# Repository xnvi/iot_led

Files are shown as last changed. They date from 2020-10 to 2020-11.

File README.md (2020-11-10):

# 1 项目简介

## 1.1 项目介绍
台灯是日常使用频率最高的电器，将给大家介绍如何制作一款可以使用微信小程序进行远程控制的智能台灯。这款台灯操作简便，可以灵活调节亮度、色温，开发板上的OLED显示屏能够实时显示台灯的状态，同时预留了WS2812灯带接口，内置多种彩灯模式，可以做氛围灯使用。所有软硬件设计全部开源，动手能力强的小伙伴也可以在此基础上改造属于你自己的智能台灯。相关问题解答参见文末Q&A章节。

## 1.2 材料清单
TencentOS_tiny_EVB_G0 开发板 x1
E53接口LED驱动模块 x1 （需要自己焊接，详细物料清单参见下方链接）
椴木板外壳一套 （需要根据图纸自己加工）
双色温LED灯管 x2 （文中同款搜索“Rohm led灯条”）
150 * 20 * 6 mm 散热器 x2
12V 1A 电源 x1 （保护环境，可以使用旧路由器、电视盒子等的电源，输出电压12V，输出电流为1A或更高）
鹅颈管 x1
鹅颈管配套铁夹 x1
鹅颈管配套螺母若干
UHU胶、电线、焊锡、电烙铁、镊子、扳手等其他材料与工具

## 1.3 项目链接
视频演示  
https://www.bilibili.com/video/bv1BK411G7cn  

工程源码  
https://gitee.com/dma/iot_led.git  

电路图及PCB  
https://oshwhub.com/Code504/e53-kuo-zhan-mu-kuai_copy  

# 2 硬件制作

## 2.1 TOS_EVB_G0 开发板
TOS_EVB_G0 开发板是由腾讯TencentOS-tiny团队设计的一款物联网开发板，外观如下：  
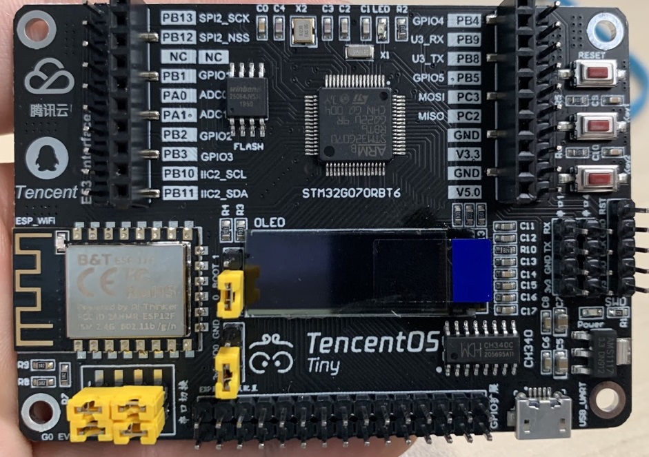
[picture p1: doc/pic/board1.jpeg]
  

* 主控芯片采用STM32G070RB，Flash空间为128KB、RAM空间为36KB；
* 板载腾讯云定制固件版ESP8266 WIFI模组；
* 板载E53传感器标准接口，方便连接各种E53传感器；
* 板载128*32 OLED显示屏幕；
* 板载8MB SPI Flash，可用于固件升级；
* 板载CH340转串口连接，可以使用一根USB线连接至电脑，查看串口日志；

下面是每部分详细的说明：  

开发板硬件电路详解  
(1) 最小系统电路  
最小系统部分由电源电路、时钟电路、Boot电路、复位电路、下载电路组成：  
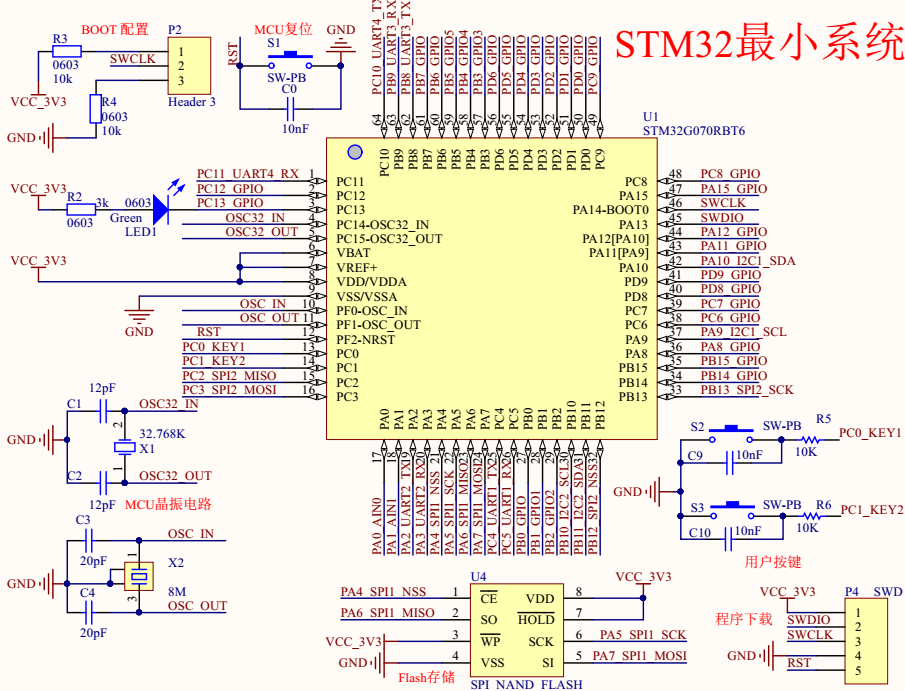
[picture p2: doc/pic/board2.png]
  

(2) WIFI电路  
WIFI部分包括ESP8266 WIFI模组供电电路、串口通信电路：  
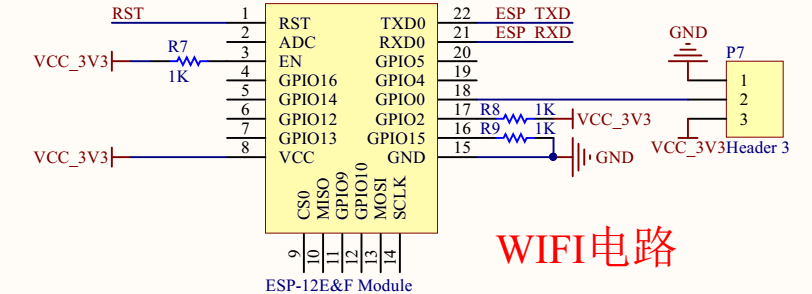
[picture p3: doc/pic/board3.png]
  

(3) E53扩展接口电路  
E53扩展接口供外部传感器连接，包括：一个串口、一个SPI接口、一个IIC接口、四个普通GPIO口、一个ADC模拟采集接口，一个DAC模拟输出接口，如图：  
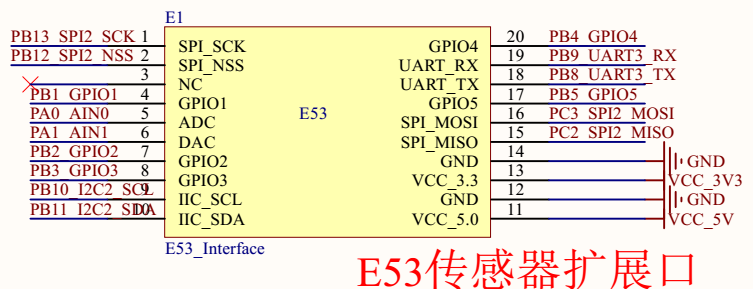
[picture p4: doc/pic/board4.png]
  

(4) USB转串口电路  
USB转串口电路将串口信息转换为USB口信号，使得开发板可以直接通过USB线连接至PC，在PC上使用串口助手查看日志：  
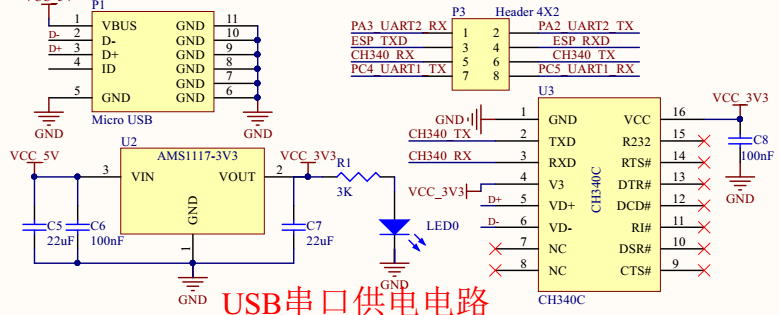
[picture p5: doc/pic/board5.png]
  

(5) OLED显示屏幕电路  
OLED屏幕部分包括OLED供电部分和通信部分：  
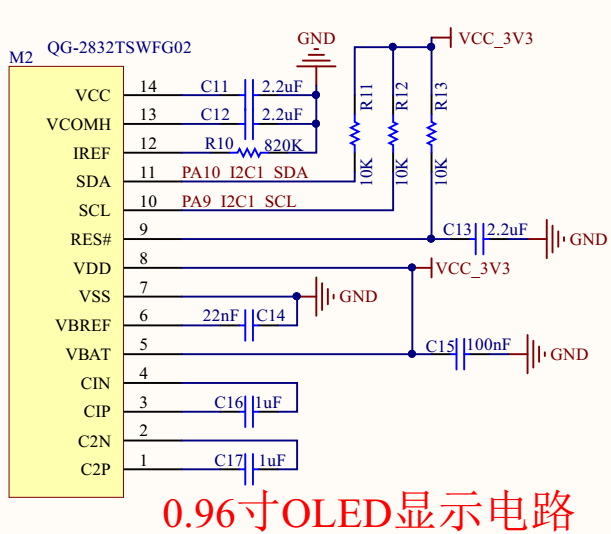
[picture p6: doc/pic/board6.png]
  

(6) 连接Micor USB线  
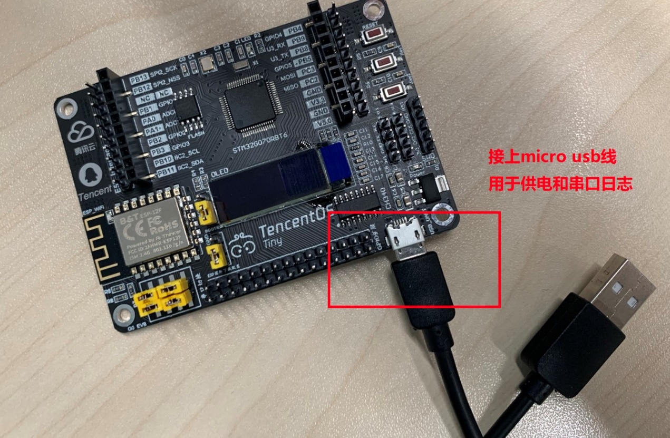
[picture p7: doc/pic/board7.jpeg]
  

(7) 连接ST-Link下载器  
开发板3v3---> STlink 3.3V  
开发板DIO---> STlink SWDIO  
开发板CLK---> STlink SWCLK  
开发板GND---> STlink GND  
请大家参考下图进行连接，千万不要接反接错，以免烧掉MCU  
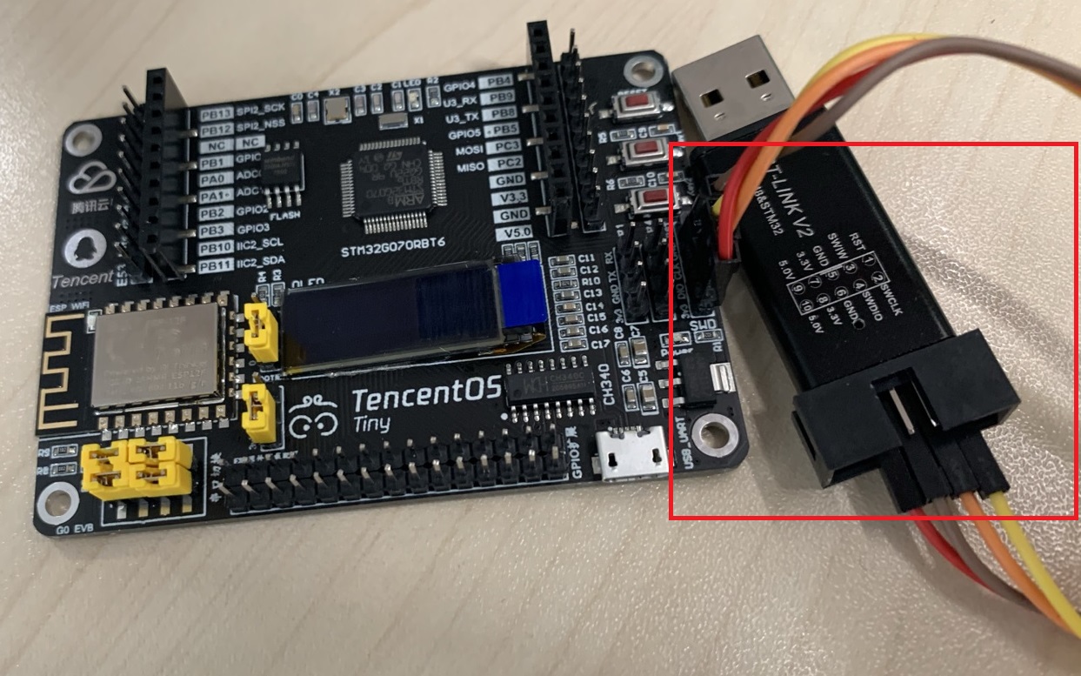
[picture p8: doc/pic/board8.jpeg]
  

## 2.2 台灯外壳及结构
首先需要购买鹅颈管、铁架、螺母等零件，规格如下:

鹅颈管建议选用40-60cm长，空心偏硬的鹅颈管，注意鹅颈管的内径不要太小，否则电线难以穿过，一定要选硬质鹅颈管，确保能够承受灯管的重量，两端螺纹规格分别为M10细牙扁头、M8细牙圆头，扁透这一端主要用于和夹子连接，圆头用于和灯管外壳连接，方便调整灯管角度，如果买不到同规格的尽量买参数相近的鹅颈管。  
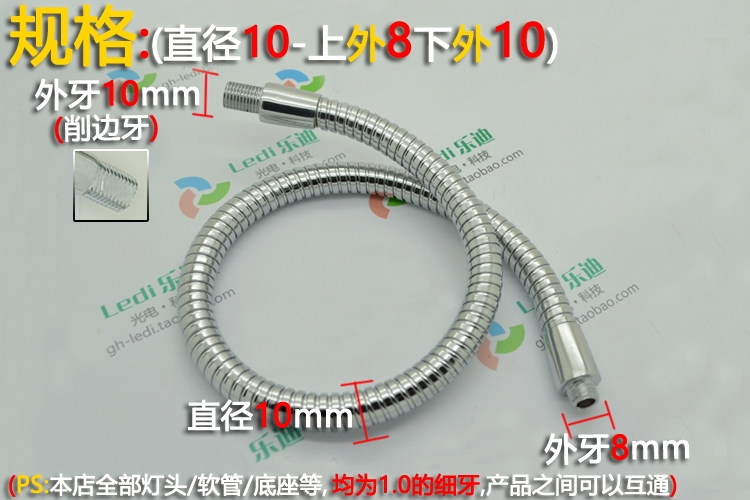
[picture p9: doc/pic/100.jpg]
  

铁夹子选购时注意开孔的形状，最好使用扁孔，这样方便固定鹅颈管，保证不会旋转，买不到扁孔和夹子和鹅颈管用圆孔的也行，记得把螺母稍微拧紧些  
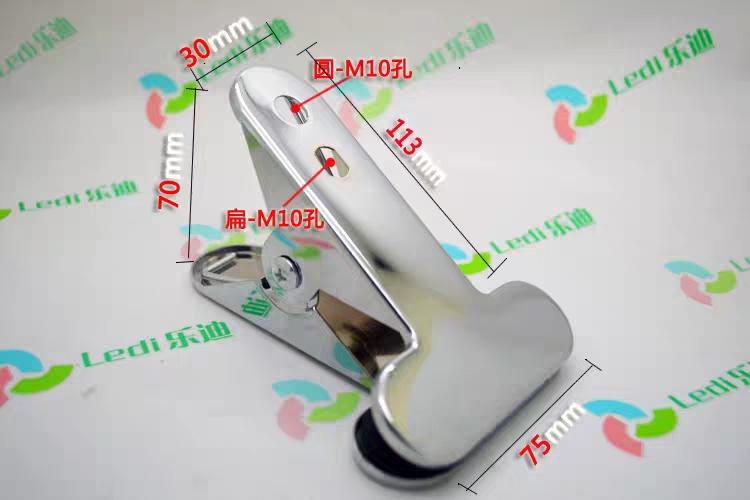
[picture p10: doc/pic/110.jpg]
  

当然还要记得买配套的螺母，有的店家会送  
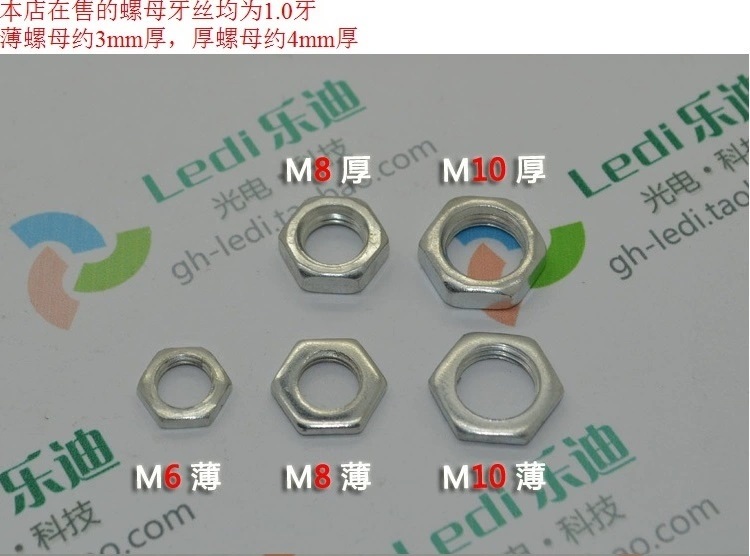
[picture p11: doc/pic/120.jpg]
  

灯管用704硅橡胶居中粘在散热器上，胶水一定不要挤得太多，胶水干透后焊接双色LED灯管（同款搜索“Rohm led灯条”），每个灯管的黄色与黄色并联，白色与白色并联  
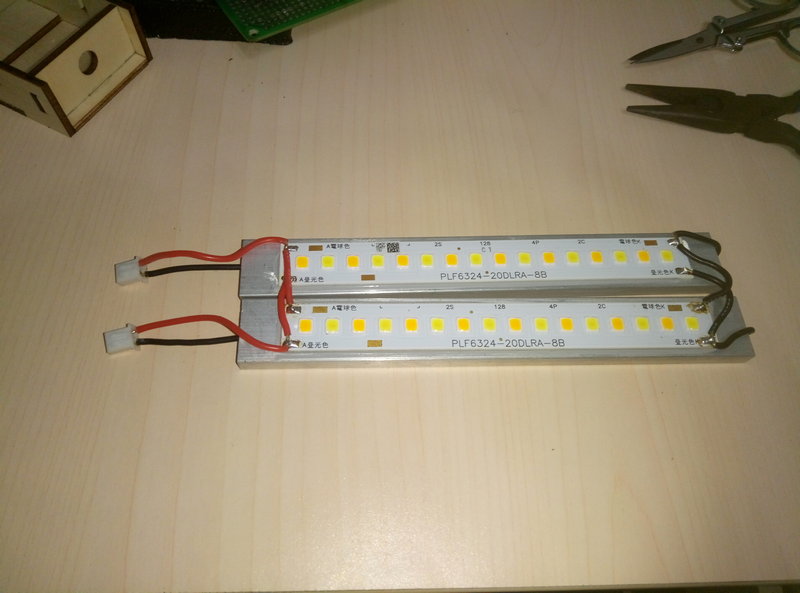
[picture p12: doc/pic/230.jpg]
  

下一步准备台灯外壳，图纸在源码的 doc 文件夹内，店家一般都是在一整块木板上进行切割，不论实际切割的大小都按整张板收费（不同店家收费可能不同，请自己与店家沟通），因此建议在一张图纸内多切割几个外壳，充分利用这块木板，减少浪费。如下图所示，这里在一块木板上切了4套台灯外壳和其他几个外壳  
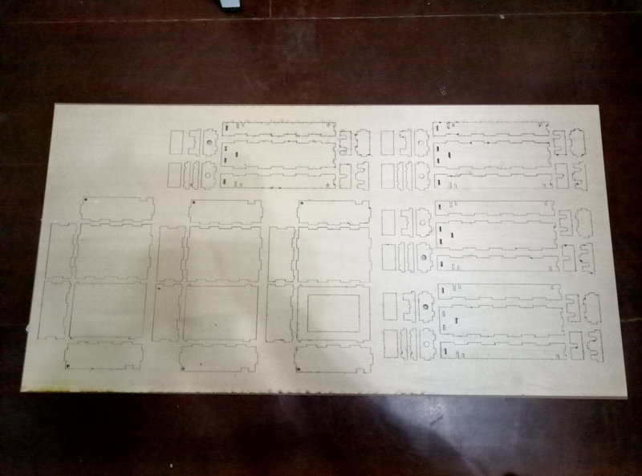
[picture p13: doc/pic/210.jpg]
  

实测单灯管照明有点暗，强烈建议用两个灯管，下图中标注的单灯管零件就不要使用了，B1和B2、G1和G2、H1和H2完全一样，F1和F2的区别在于开孔的直径不一样，一个是8mm，另一个是10mm，如果买不到同规格的鹅颈管方便替换使用
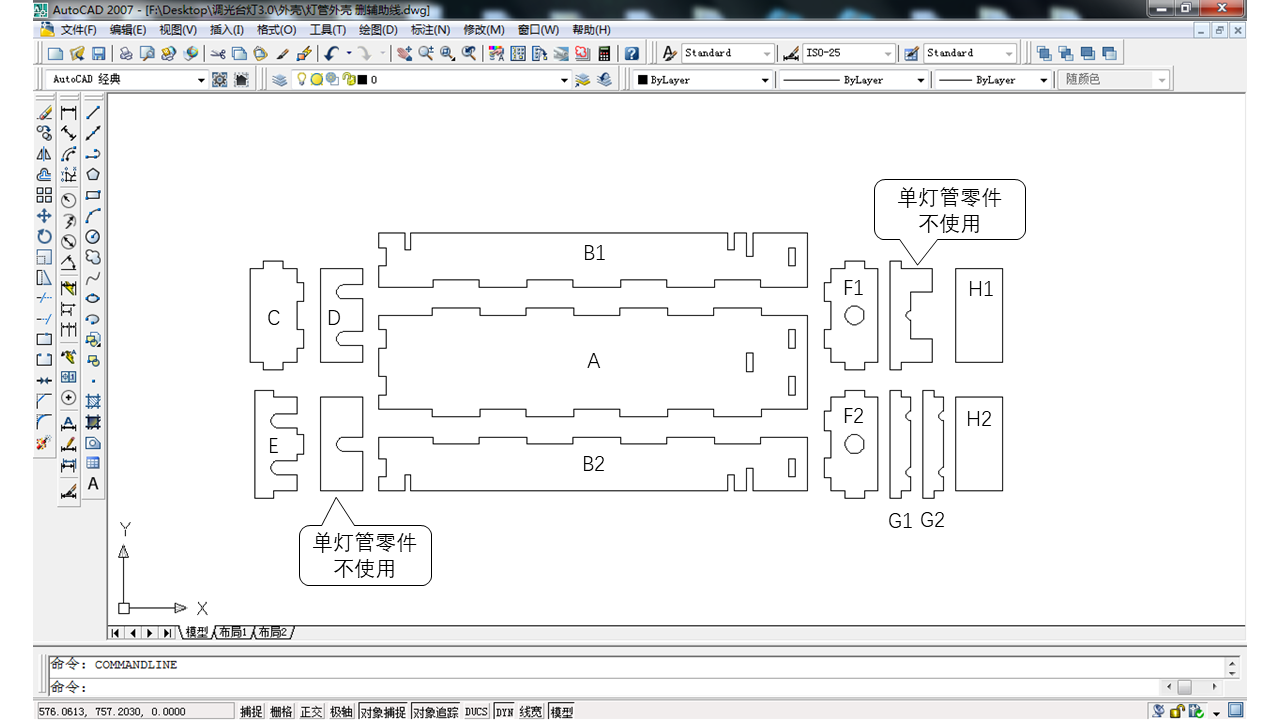
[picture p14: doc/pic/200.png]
  

将H1、H2粘在A上，这一步的主要目的是增加外壳的整体厚度，确保F1和F2开孔处有一定的轻度，否则开孔与边框离得太近很容易断
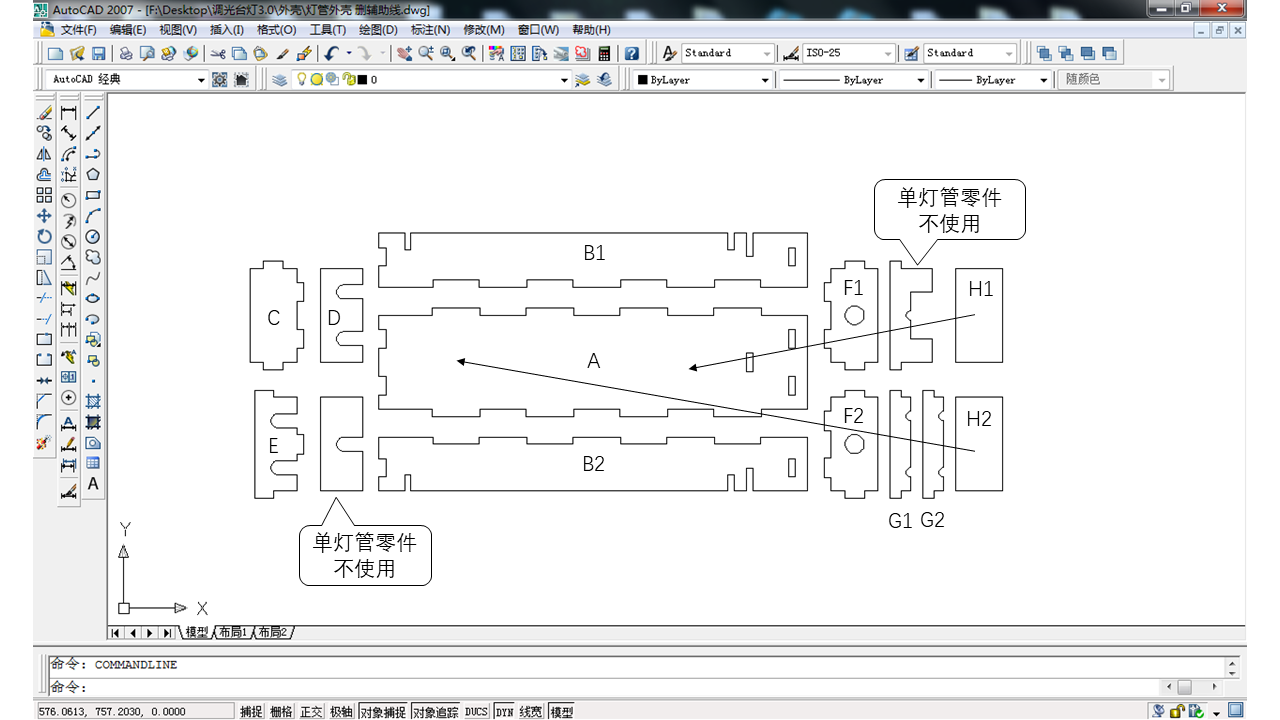
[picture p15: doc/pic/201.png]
  

将F1或F2按图纸箭头所示插入A对应孔内，B1和B2分别竖着安装在A的两侧，同时将F1或F2插入孔内，将C与D对齐粘在一起，将C按箭头所示进行组装  
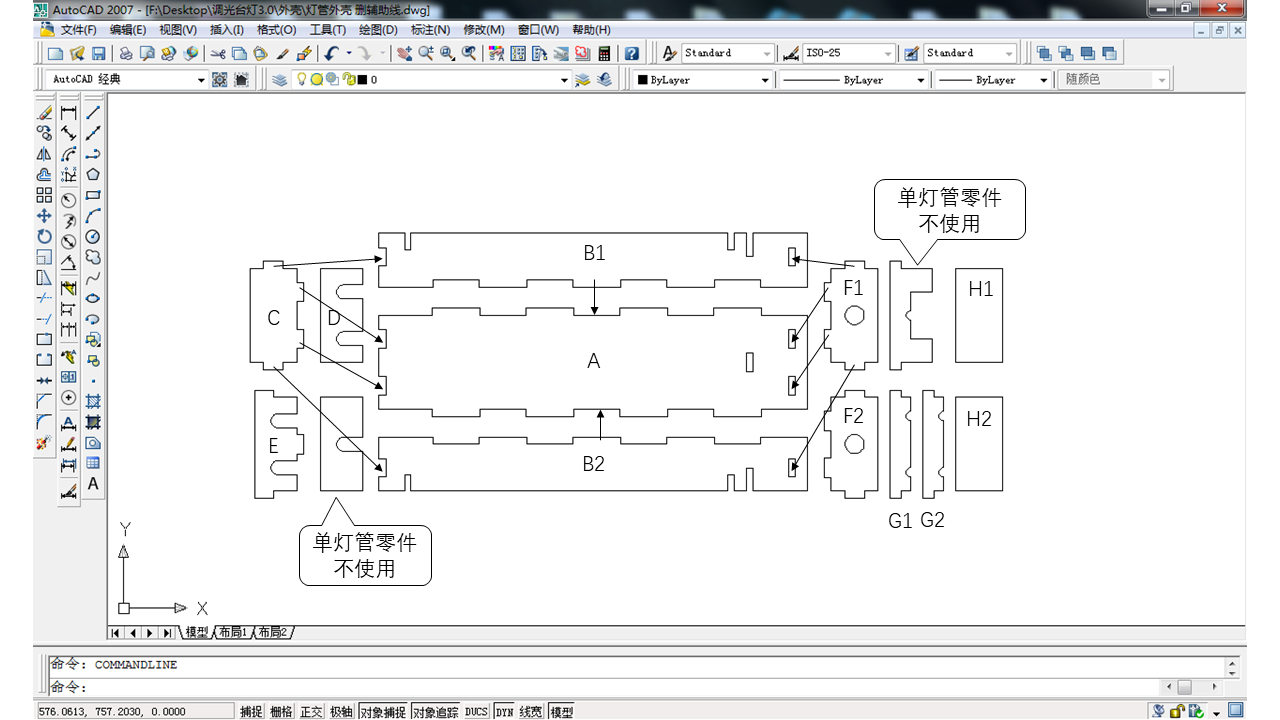
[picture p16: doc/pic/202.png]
  

等前几步的胶水干透以后，将灯管放入外壳，并将电线从E预留的孔中穿过，最后将E按照箭头所示进行安装  
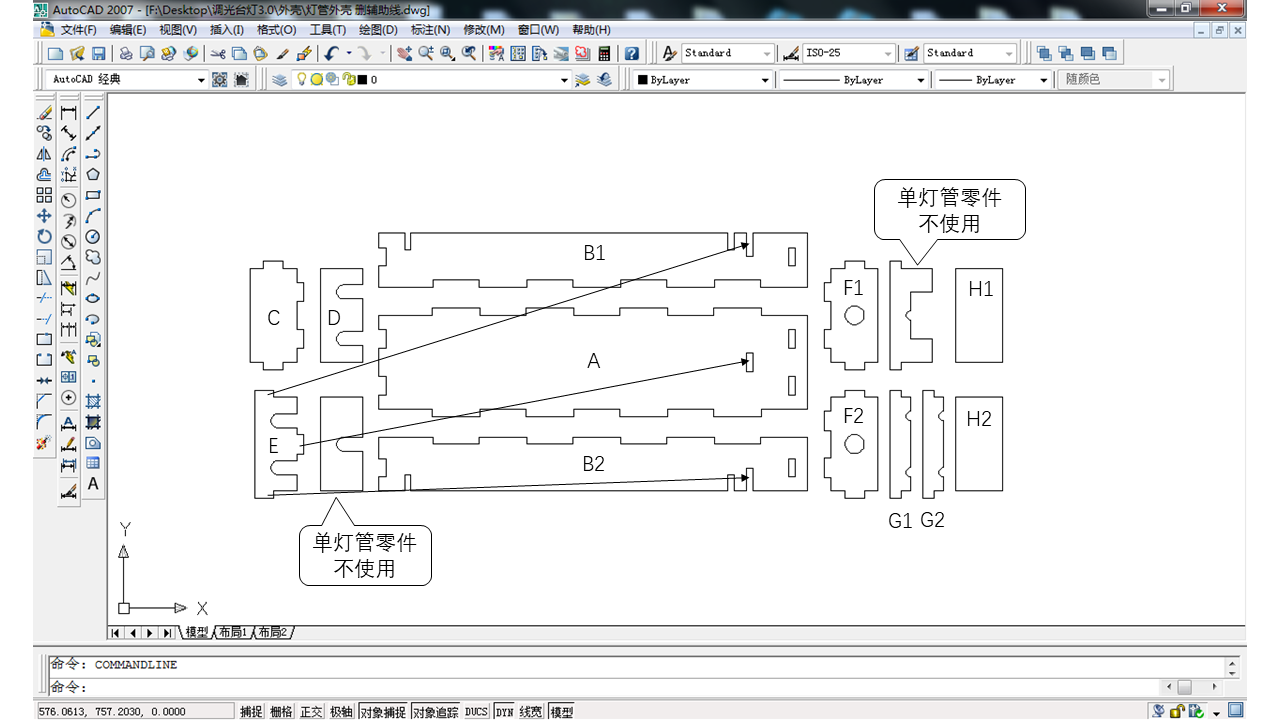
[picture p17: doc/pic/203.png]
  

最后将G1、G2按箭头所示进行安装，电线同样需要从预留的凹槽中穿过
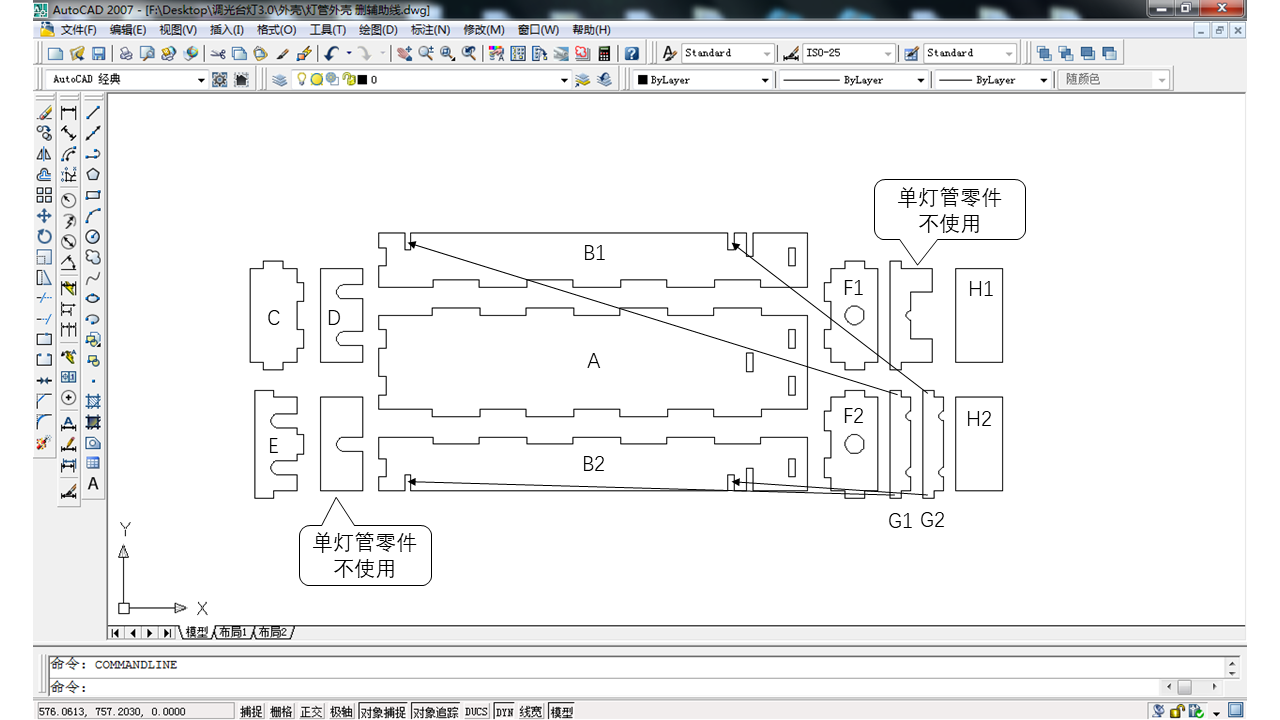
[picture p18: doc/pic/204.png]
  

在组装之前建议先按下图所示摆放一遍，确保没有拿错零件，最后再进行完整组装
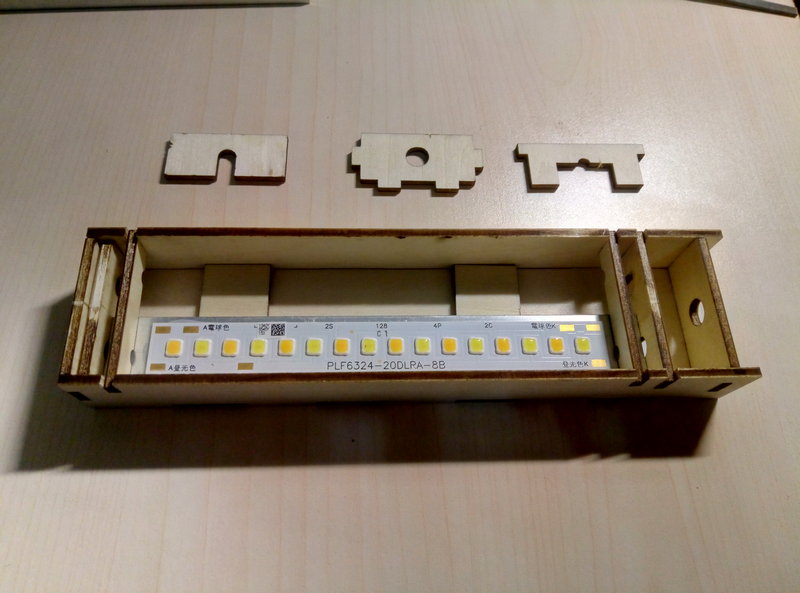
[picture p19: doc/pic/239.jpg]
  

最后组装完成是这样的，供大家参考，安装时一定注意先后顺序，提前把线、螺母穿好，避免返工  
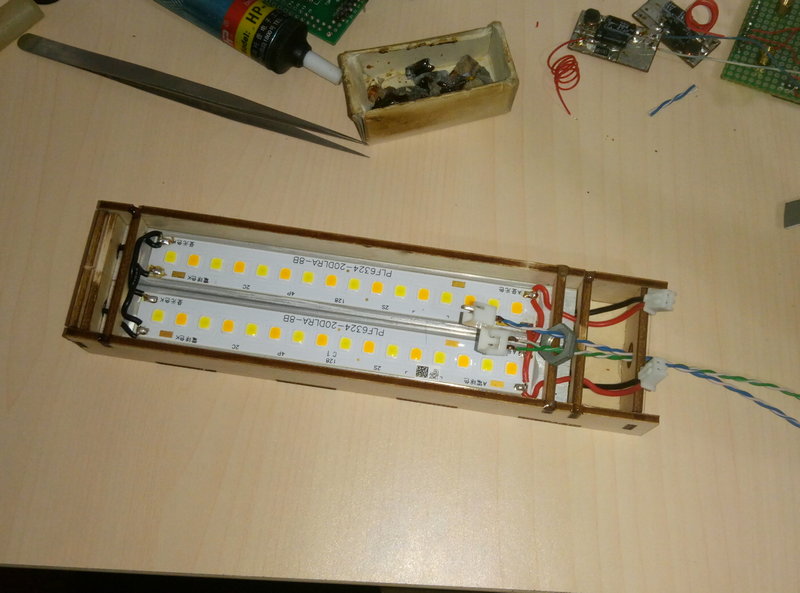
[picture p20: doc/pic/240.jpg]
  

上图有一个细节，我的外壳边缘比中间的零件大概高出2mm，预留用于安装透明外壳。如果买了什么东西的包装盒是塑料磨砂材质，可以裁剪一块合适大小盖在灯管外壳上，这样光线会柔和一点，不至于太刺眼。实在没有可以不装，如果不差钱也可以按尺寸找商家切割一块2mm厚的雾面亚克力。

**注意事项**
不同商家的木板厚度有一定误差，切割机也有一定误差，请提前沟通，误差一般在0.1-0.2mm左右，可能需要在图纸中进行补偿

## 2.3 E53接口LED驱动模块
请根据原理图内物料清单采购元件并焊接，模块焊接完成如图  
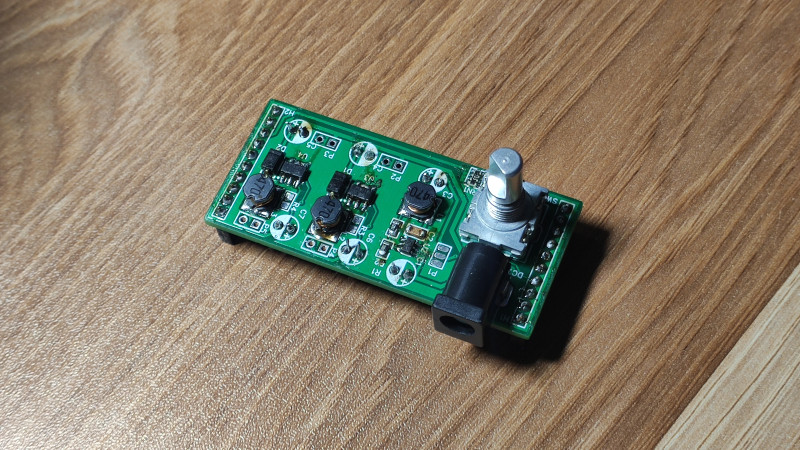
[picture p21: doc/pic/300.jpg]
  
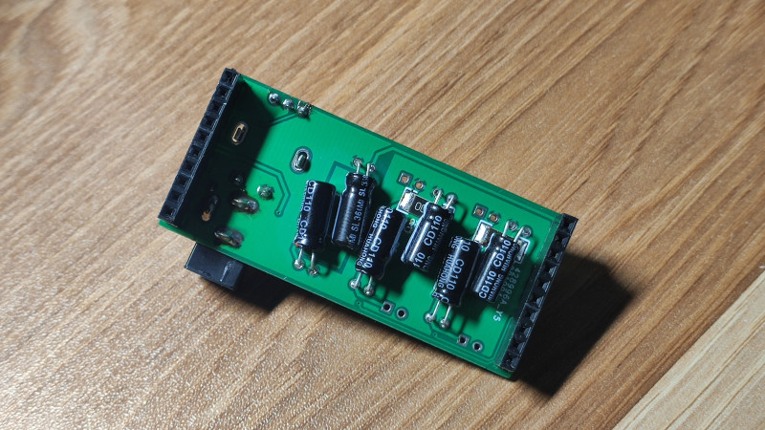
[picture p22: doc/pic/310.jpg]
  

请按下图所示与开发板进行组装
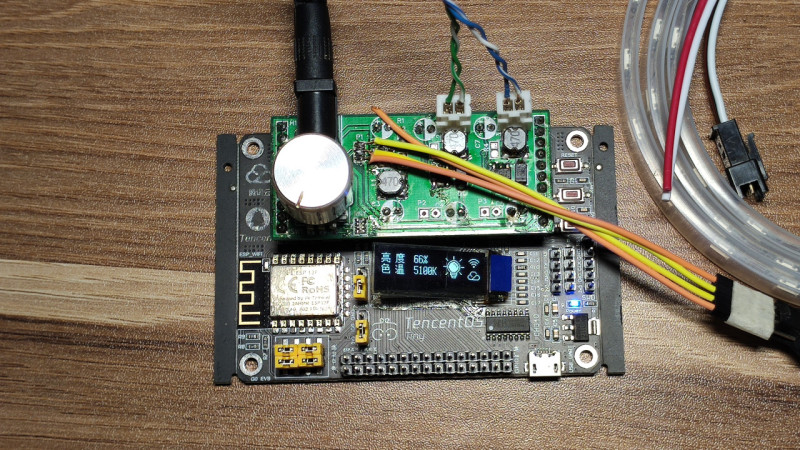
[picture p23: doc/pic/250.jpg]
  

**注意事项**
1. 板子上预留WS2812灯带的接口，没有灯带或不需要灯带可以不焊。  
2. 不使用灯带或WS2812灯珠数量少于5个，建议采用线性稳压方案；超过5个建议采用开关稳压方案。  
3. 板子上有两路PT4115驱动，如果使用双色灯管，左边一路接黄色，右边一路接白色。如果使用单色灯管，建议只接右边一路，并把色温调整到6500K，这样使用的缺点就是浪费了一路驱动，想要驱动两路白光LED，请自行修改的代码，删除调整色温的相关内容。  
4. 灯管的功率计额定电压决定了PT4115的采样电阻，目前用的是两根双色温灯管，单根灯管额定电压6V，单色额定电流300mA，这里是两根灯管的黄色与黄色并联、白色与白色并联，单色温的总额定电流为600mA，根据PT4115手册计算出0.2ohm采样电阻输出电流为500mA，因此串联两个0.1ohm的采样电阻。如果使用其他规格的灯管请自行计算采样电阻阻值。  
5. 旋转编码器旁边有一个排阻，为IO口上拉，如果单片机支持上拉可以不焊。  
6. P2、P3、R3、R4为预留测试焊盘，不需要焊接。  
7. 设计输入电压为12V，如需驱动更高电压、更大功率的LED灯管，请注意元件耐压，可能需要更换更高耐压的元件。  

# 3 软件开发

## 3.1 ESP8266烧写腾讯云定制固件

### 3.1.1 下载固件
腾讯云IoT AT指令是一套针对使用通讯模组（2G/4G/NB/WIFI）接入腾讯云物联平台的定制AT指令集，如果通讯模组实现了该指令集，则设备接入和通讯更为简单，所需代码量更少。 ESP8266作为IoT领域使用最广泛的一款WiFi芯片/模组，腾讯云在其通用AT指令基础上，增加了腾讯云IoT AT指令集，形成一个定制的模组固件QCloud_IoT_AT_ESP8266。  
下载链接：https://github.com/tencentyun/qcloud-iot-esp-wifi  
使用git下载的命令如下：  
`git clone https://github.com/tencentyun/qcloud-iot-esp-wifi.git`
下载之后即可在图中圈出的文件夹中看到定制固件：  
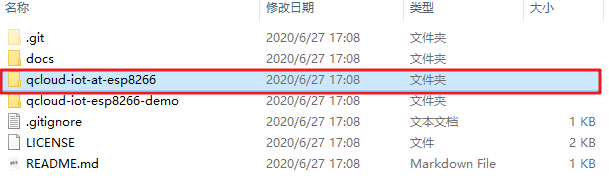
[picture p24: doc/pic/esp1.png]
  

### 3.1.2 下载烧写工具
使用乐鑫官方下载工具ESPFlashDownloadTool，下载链接如下：  
https://www.espressif.com/zh-hans/support/download/other-tools  
点击下载Flash 下载工具（ESP8266 & ESP32 & ESP32-S2）：  
  
下载之后解压即可。  

### 3.1.3 固件说明
腾讯云IoT定制的AT模组固件QCloud_IoT_AT_ESP8266，适用于所有FLASH大小为2MB或者2MB以上的ESP8266模组。  
AT串口使用UART0，默认的Tx为GPIO1，Rx为GPIO3。但因为ESP8266的UART0 默认会在上电启动期间输出一些打印，如果打印信息影响设备功能，可在上电期间将 U0TXD(GPIO1)、U0RXD(GPIO3) 分别与 U0RTS (GPIO15)，U0CTS(GPIO13)进行交换，以屏蔽打印。因此提供两个版本的固件：  
* 名称包含UART_1_3的固件串口使用的Tx为GPIO1，Rx为GPIO3。  
* 名称包含UART_15_13的固件串口使用的Tx为GPIO15，Rx为GPIO13。  
进入QCloud_IoT_AT_ESP8266_FW，本文中我们使用第一个固件：  
  

### 3.1.4 烧写固件
切换boot选择端子和串口选择端子  
(1)将开发板上的ESP8266启动引脚配置端子切换到低电平；  
(2)将开发板上的串口选择端子置于中间，使ESP8266直接与PC串口连接：  
方法参考下图：  
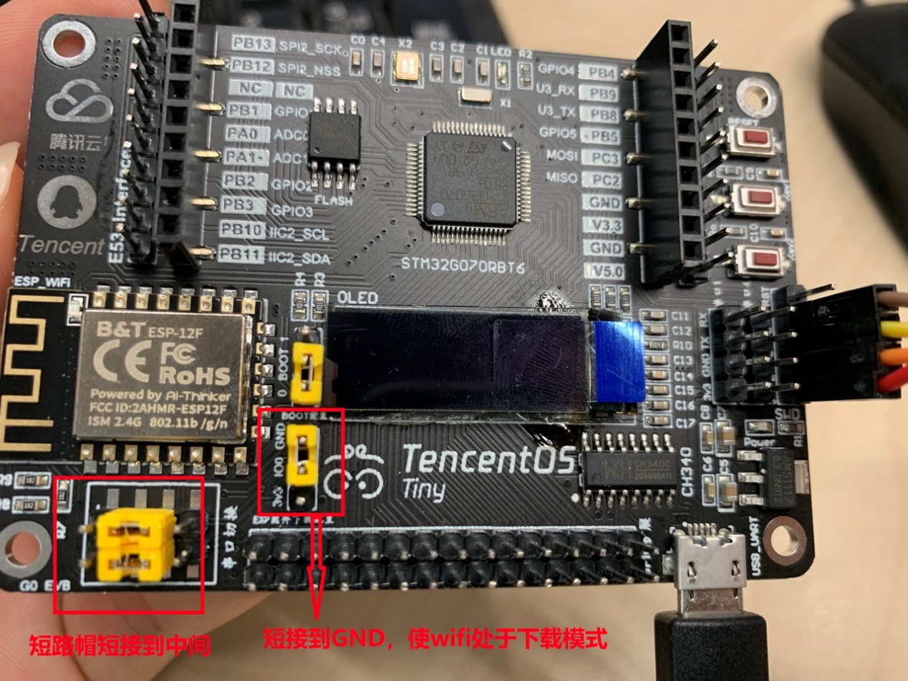
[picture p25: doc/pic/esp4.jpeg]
  
 
运行Flash烧写工具  
双击工具，运行：  
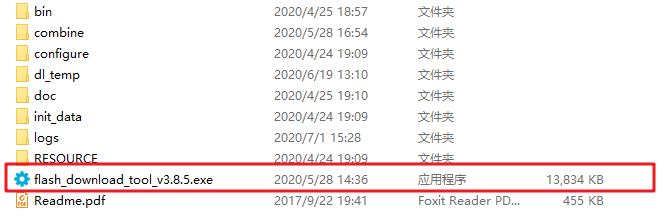
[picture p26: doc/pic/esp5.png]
  

选择开发者模式：  
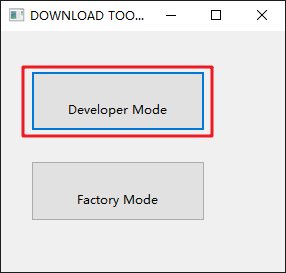
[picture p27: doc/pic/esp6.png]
  

选择ESP8266下载工具：  
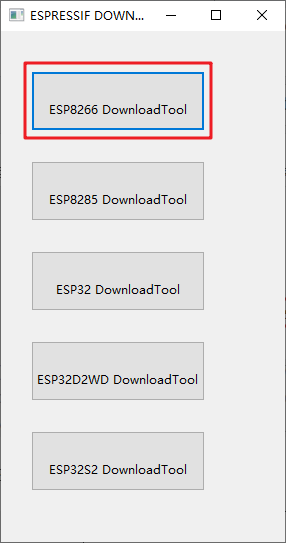
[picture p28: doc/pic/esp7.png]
  

开始下载  
按照图中进行操作：  
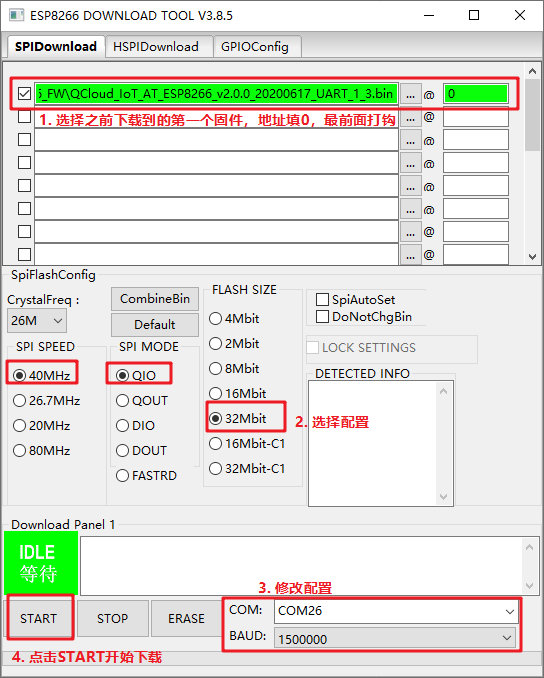
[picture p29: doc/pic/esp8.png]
  

点击下载之后，按下开发板上的复位键，Flash下载工具开始下载：  
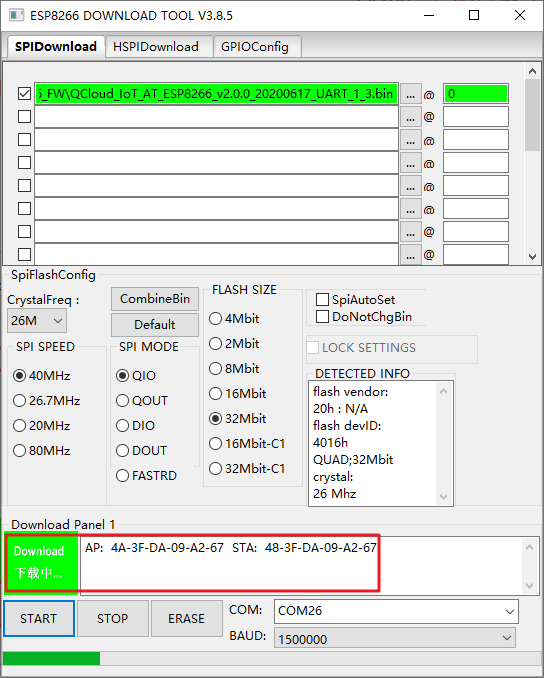
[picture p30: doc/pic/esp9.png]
  

若没有显示，请检查接线端子是否连接正确。  

下载完成  
下载完成之后如图：  
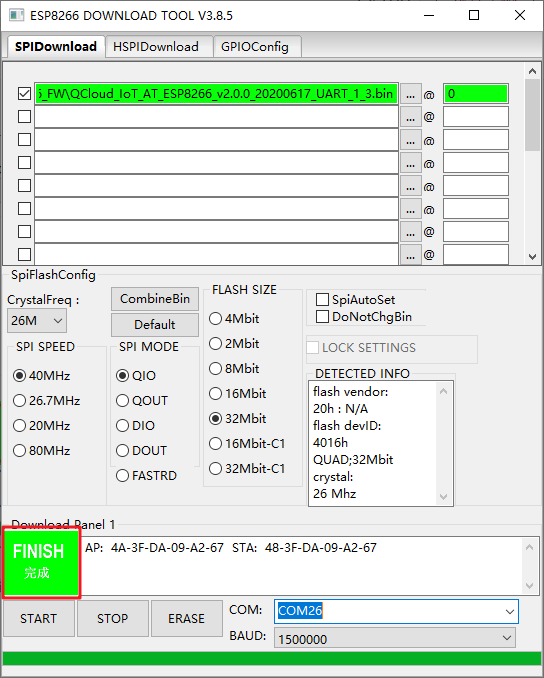
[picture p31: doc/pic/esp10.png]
  

关闭工具，将boot选择引脚拔下，将串口选择端子恢复默认。  

注意：完成固件下载后，一定切记将跳线端子恢复到默认状态，默认端子怎么短接可以参考前面完整的组装成品图，否则wifi将没法工作，MCU也没法控制wifi。  

## 3.2 工程代码修改与使用
下载TencentOS代码 https://github.com/Tencent/TencentOS-tiny.git  

下载本工程代码 https://gitee.com/dma/iot_led.git  

把本工程代码放在 `TencentOS-tiny\board\TencentOS_tiny_EVB_G0\KEIL`下  

本工程使用的是AT SDK，已经集成在工程下，因为部分功能的需要，我在官方SDK的基础上做了一些修改及适配，源码在这里 https://github.com/tencentyun/qcloud-iot-sdk-tencent-at-based  

如需移植其他OS或开发板请参阅官方文档自行修改。  

在腾讯物联网开发平台创建设备，具体步骤参见 https://cloud.tencent.com/document/product/1081/34738  

产品定义，新建项目，新建产品，按如下配置  
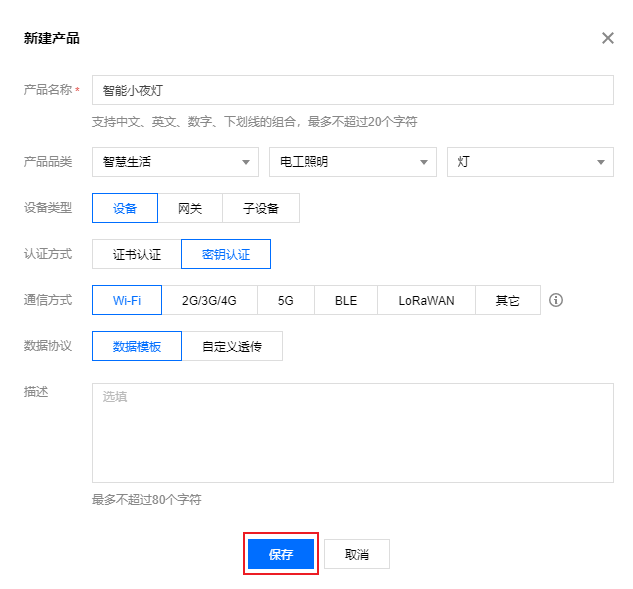
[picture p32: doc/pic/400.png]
  

数据模板，选择“导入json”，json文件路径 `iot_led\user_code\智能灯.json`，你也可以添加自己的功能，或在此基础上进行二次开发  
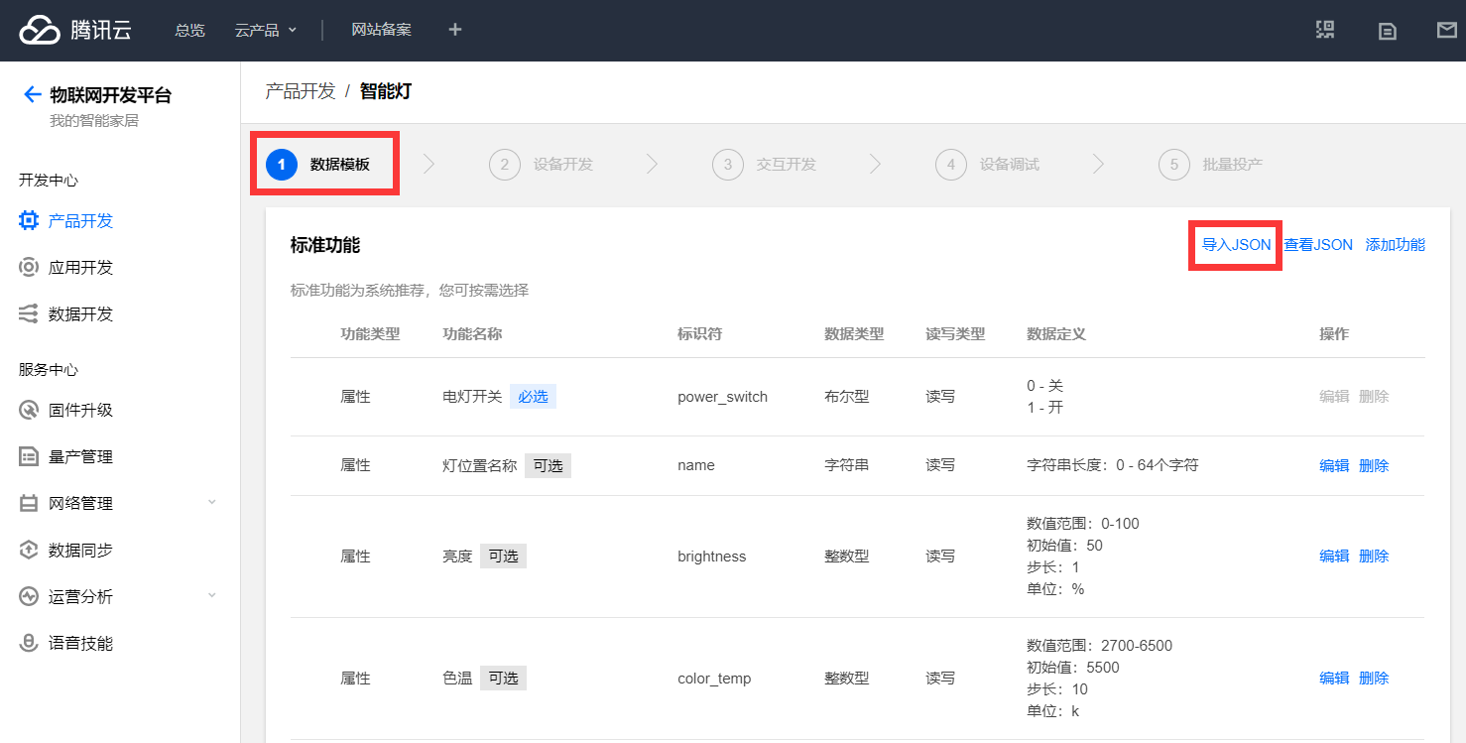
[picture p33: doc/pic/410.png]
  

没有修改json的话可以略过这一步，如果你之前在数据模板中添加了自己的功能或有其他修改，请点击“查看json”然后导出
，将导出的json放在`iot_led\qcloud-iot-sdk-tencent-at-based\tools`，cmd窗口运行`python codegen.py -c 你导出的数据模板.json`，重新生成数据模板代码，如果提示出错，请检查编码是否为GBK，将生成几个c文件放入 `iot_led\qcloud-iot-sdk-tencent-at-based\usr_logic`，打开 `iot_led\qcloud-iot-sdk-tencent-at-based\usr_logic\data_template_usr_logic.c`，在 `static void deal_down_stream_user_logic(void *pClient, ProductDataDefine * pData)` 中开发你自己的功能。  

交互开发，面板配置这里按自己的需求摆放各个组件、设置图标等，点击左边的箭头可以设置图标顺序，样式和图标可以按自己的喜好进行更改，也可以照搬这个设计  
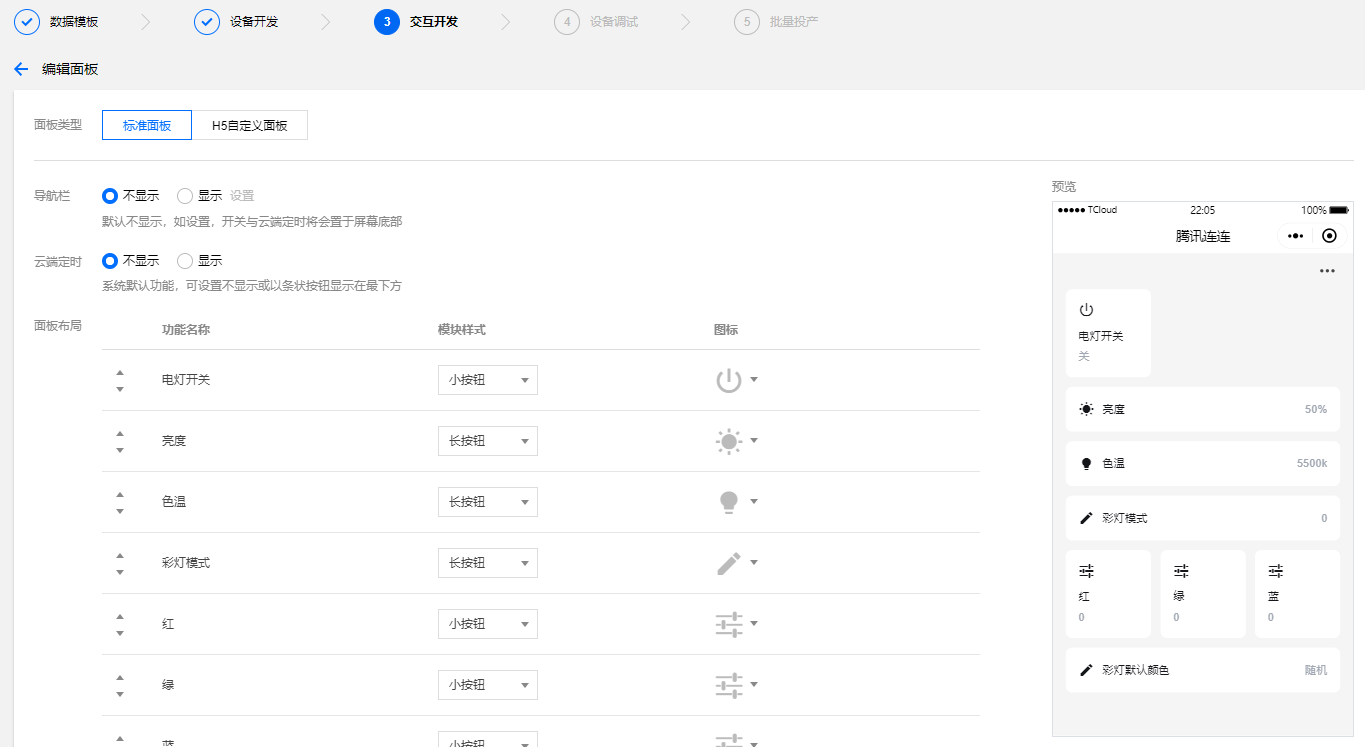
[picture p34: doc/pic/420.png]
  

设备调试，设备端代码编译并下载后你可以在这里在线调试  

打开 `iot_led\user_code\user_config.h`
找到你刚刚创建的设备，填入设备密钥、产品ID、设备名  
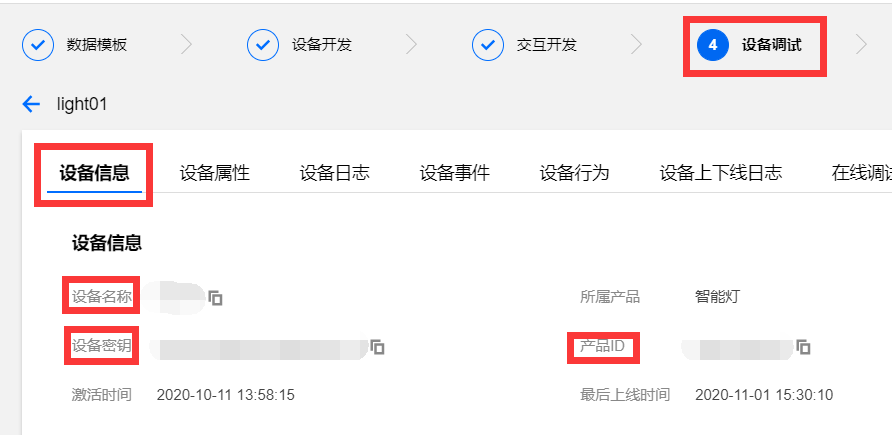
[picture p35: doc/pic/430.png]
  

填入你家的wifi名和密码（如果作为一个真正商用的产品，应该通过配网或其他方式来获取wifi信息，不应该在代码中写wifi名和密码，因为你不可能知道用户家的wifi，目前配网功能有，但还不完善，就先这样用吧）  

打开`TencentOS-tiny\board\TencentOS_tiny_EVB_G0\BSP\Inc\stm32g0xx_hal_conf.h`打开这处宏 
`/* #define HAL_TIM_MODULE_ENABLED   */`  

打开`TencentOS-tiny\board\TencentOS_tiny_EVB_G0\TOS_CONFIG\tos_config.h`
修改`#define TOS_CFG_TASK_DYNAMIC_CREATE_EN  0u`为``#define TOS_CFG_TASK_DYNAMIC_CREATE_EN  0u``
由于启用了动态创建任务，任务栈会从对内存申请，所以系统堆内存适当改大一点，避免溢出`#define TOS_CFG_MMHEAP_DEFAULT_POOL_SIZE        0x2000`  

最好结合自己的代码，在系统完全运行起来以后使用`k_err_t tos_mmheap_check(k_mmheap_info_t *info);`查看内存使用情况，适当修改对内存的大小。如果出现莫名其妙的死机、重启等问题，大概率是内存不足溢出了。  

打开
`TencentOS-tiny\board\TencentOS_tiny_EVB_G0\BSP\Src\stm32g0xx_it_module.c`
添加头文件`#include "hal_at.h"`
添加`extern sRingbuff g_ring_buff;`  
修改
```
void HAL_UART_RxCpltCallback(UART_HandleTypeDef *huart)
{
    /* data is defined in usart.c */
    extern uint8_t data;
    
    if (huart->Instance == USART2) {
        HAL_UART_Receive_IT(&huart2, &data, 1);
        tos_at_uart_input_byte(data);
    }
}
```
如下
```
void HAL_UART_RxCpltCallback(UART_HandleTypeDef *huart)
{
    /* data is defined in usart.c */
    extern uint8_t data;
    
    if (huart->Instance == USART2) {
        HAL_UART_Receive_IT(&huart2, &data, 1);
        // tos_at_uart_input_byte(data);
        ring_buff_push_data(&g_ring_buff, &data, 1);
    }
}
```

编译下载运行  

# 4 使用演示
设备菜单选择配网，打开微信，在主页面下拉，搜索“腾讯连连小程序”，点击加号添加设备，在电工照明中选择灯，按照提示进行配网。详细操作步骤请看视频演示  
https://www.bilibili.com/video/bv1BK411G7cn  

# 5 Q&A
Q: 为什么不用github而使用gitee？  
A: 以国内的网络状况使用github经常出现“我上传不上去，你下载不下来”的情况，gitee就不存在这个问题，顺便支持一下国产。  

Q: TencentOS的代码太大了，国内网络状况也不咋地，git clone总是失败怎么办？  
A: 使用gitee新建一个仓库，选择导入已有仓库并填入 `https://github.com/Tencent/TencentOS-tiny.git` 待后台同步完成后就可以像github一样使用了，速度飞快。  

Q: E53模块及开发板如何供电？  
A: 使用12V电源接入E53模块即可，TOS_EVB_G0开发板及E53模块自身的5V电源来自E53模块降压，TOS_EVB_G0开发板及E53模块自身的3.3V电源来自TOS_EVB_G0开发板的降压。  

Q: E53模块供电能力如何？  
A: 按目前的设计方案，SY8120B1ABC最大输出电流为2A，如需驱动更多WS2812灯珠，或给其他大功率负载供电请更换其他pin to pin兼容的芯片，并按芯片要求选取合适的外围元件。手头暂时没有合适的电感，图片中使用的是一颗47uH电感，且内阻较大，实测输出电流超过600mA时电感发热严重。  

Q: E53模块驱动LED灯条有哪些注意事项？  
A: 目前设计方案供电电压为12V，最高建议不要超过15V。12V情况下可以驱动的3V、6V、9V的LED灯珠或灯条。由于PT4115是降压型LED驱动芯片，理论化输入电压要高于LED的额定电压，实测起始可以驱动12V的LED灯条，但是效果不太理想，不建议这么使用。单路PT4115最大输出电流为1A，注意LED灯条的功率，并修改合适的采样电阻。  

Q: PT4115的采样电阻如何取值？  
A: 实际采样电阻的取值请根据你的LED灯条额定功率进行计算，E53模块上的PT4115驱动预留两个采样电阻焊盘，你可以采用短路一个焊盘、两个电阻串联、两个电阻叠焊等各种手段组合出各种阻值。阻值与限流关系计算公式为`Iout = 0.1 / RS (RS ≥ 0.082 ohm)`，其中Iout为占空比100%时的输出电流，即最大输出电流，更多内容详见PT4115数据手册。  

Q: 如果采用12V以上的输入电压，有哪些注意事项？  
A: 注意更换更高耐压的电容及芯片，降压芯片SY8120B1ABC的最高输入电压为18V，请更换其他更高耐压的pin to pin兼容芯片，例如SY8291ABC、SY8401ABC、ME3116AM6G、LM2841XBMKX等，更多芯片可以上立创商城选购。  

Q: 线性稳压和开关稳压该如何选择？  
A: 大功率5V负载如驱动5颗以上的WS2812建议使用开关稳压方案，否则请使用线性稳压方案，可使用AMS1117-5.0或HT7150-1等，AMS1117的最高输入电压为18v，HT7150最高输入电压为30V，请根据输入电压选型，线性稳压与开关稳压共用C1、C3电容。  

Q: 为什么亮度设置在2%时灯管不亮？  
A: PT4115的有效占空比范围在4%-100%之间，4%以下会认为关闭，不同批次芯片性能也略有差异，详见PT4115数据手册。  

Q: 如果我使用12V供电想要驱动18V或更高电压的LED灯管该怎么办？  
A: 目前的方案为降压型LED驱动，不支持升压，如有需要可采用SY7200AABC等升压型LED，电路图及PCB请自行修改，暂时没有成品设计方案。  

Q: 这么多的灯光效果是如何实现的？  
A: 基于github开源项目 [WS2812FX](https://github.com/kitesurfer1404/WS2812FX) ，适配arduino接口，将源代码cpp修改并适配为c语言，比较简单粗暴，参见 [WS2812FX_C_Lang](https://gitee.com/dma/ws2812fx_c_lang)  

Q: 这个模块可以用在TencentOS_tiny_EVB_LX、TencentOS_tiny_EVB_MX_Plus等开发板上吗？  
A: 目前只保证在TencentOS_tiny_EVB_G0上工作正常，其他开发板可能需要移植部分代码，注意修改管脚PWM输出、WS2812驱动时序等，部分开发板对应E53接口的GPIO4及GPIO5可能无法输出硬件PWM，可以考虑软件PWM或者从可以输出PWM的引脚飞线。  

Q: 哪里可以获得TencentOS_tiny_EVB_G0开发板呢？  
A: 我也不知道呀，我这块板子是活动得到的，在国内某著名电商网站搜“物联网俱乐部”，这家店可能有的卖。如果没有的话要不你自己照着原理图画一个？  

Q: 路由器器重启后设备就掉线了，有什么解决办法？  
A: 官方ESP8266定制固件暂不支持wifi掉线自动重连，只能重启设备等待自动重连，如果你知道wifi密码的话，也可以在代码中调用`AT+CWJAP`命令进行重连。  

Q: 打算出成品吗？或者做小批量？  
A: 个人精力有限，不论是E53模块还是整套台灯都不打算出成品或小批量，所有设计方案全部开源，有兴趣可以自己制作，觉得我的方案用着不爽欢迎自己改造，不想动手做的可以直接买品牌智能台灯。手头剩余的几块PCB可能会送给朋友及同事。  

Q: 为什么开源发布的原理图和PCB与你文章中展示的不一样？  
A: 部分与SY8120B1ABC pin to pin兼容的芯片需要续流二极管，而SY8120B1ABC不需要，因此在原理图及PCB中添加了这个二极管，不影响使用。  

Q: 为什么设备重启、上电时灯会闪一下？  
A: 这与MCU与LED驱动芯片有关，stm32的GPIO上电默认浮空输出，而PT4115的控制引脚内部带有一个1.2M的上拉电阻，在stm32的GPIO还没有初始化并拉低时会点亮LED灯。解决方法：可以在预留的焊盘上焊接一个合适的下拉电阻，本方案中这个电阻取值，大约在50K-100K左右，注意电阻的取值不能过小，以免MCU的GPIO驱动能力不足导致无法拉高而点不亮LED灯  

Q: 能提供技术支持吗？  
A: 个人精力有限，随缘吧！  

Q: 这个方案能商用吗？  
A: 请遵守开源协议。

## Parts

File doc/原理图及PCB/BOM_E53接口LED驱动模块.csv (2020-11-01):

ID | Name | Designator | Footprint | Quantity | Manufacturer Part | Manufacturer | Supplier | Supplier Part | LCSC Assembly
1 | Header-Female-2.54_1x2 | P4,P2,P5,P3 | HDR-1X2/2.54 | 4 | 2.54-1*2PFemale | BOOMELE | LCSC | C49661
2 | SS34_C8678 | D3 | DO-214AC_L4.3-W2.7-LS5.3-RD | 1 | SS34 | MDD | LCSC | C8678 | Yes
3 | SY8120B1ABC | U2 | SOT-23-6_L2.9-W1.6-P0.95-LS2.8-BR | 1 | SY8120B1ABC | Silergy | LCSC | C88474 | Yes
4 | 220K | R2 | R0805 | 1 | 0805W8F1544T5E | Uniroyal Elec | LCSC | C422787
5 | 30K | R1 | R0805 | 1 | 0805W8F1544T5E | Uniroyal Elec | LCSC | C422787
6 | 10K | RN1 | RES-ARRAY-SMD_0603-8P-L3.2-W1.6-BL | 1 | 4D03WGJ0472T5E | UniOhm | LCSC | C1980 | Yes
7 | EC11E18244AU | SW1 | SW-DIP-11.7X12 | 1 | EC11E18244AU | ALPS Electric | LCSC | C202365
8 | PT4115 | U3,U4 | PT4115 | 2 | PT4115B89E-B | CR-PowTech(Shanghai) | LCSC | C15425
9 | Header-Male-2.54_1x3 | H3 | HDR-TH_3P-P2.54-V | 1 | Header2.54mm 1*3P | BOOMELE | LCSC | C49257
10 | DC005-T | DC1 | DC-IN-TH_DC005-T | 1 | DC005-T | SHOU HAN | LCSC | C431532
11 | AMS1117-5.0_C351787 | U1 | SOT-223_L6.5-W3.5-P2.30-LS7.0-BR | 1 | AMS1117-5.0 | PUOLOP | LCSC | C351787
12 | 1u | C4,C6,C5,C7 | CAP-5*11 | 4
13 | 4.7u | C3 | CAP-5*11 | 1
14 | 22u | C1 | CAP-5*11 | 1
15 | 33u | L2,L3 | IND-5845 | 2
16 | 10u | L1 | IND-5845 | 1
17 | 0.1u | C2 | C0805 | 1
18 | E53_Interface_A | H1 | HDR-TH_10P-P2.54-V | 1 | Headers Pins2.54mm1*10P |  | LCSC | C57369
19 | 10k | R3,R4 | R0805 | 2
20 | 0.1 | R5,R6,R7,R8 | R2512 | 4
21 | E53_Interface_B | H2 | HDR-TH_10P-P2.54-V | 1 | Headers Pins2.54mm1*10P |  | LCSC | C57369
22 | 1N5819 | D1,D2 | SMA_L4.4-W2.6-LS5.0-RD | 2 | MBR0520LT1G | ON | LCSC | C23848 | Yes

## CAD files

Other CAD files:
doc/灯管外壳.dwg

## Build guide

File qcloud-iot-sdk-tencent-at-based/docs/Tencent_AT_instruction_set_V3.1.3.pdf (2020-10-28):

# 腾讯云 IoT MQTT AT 指令

腾讯机密，严禁外传。
未经授权，请勿扩散。

## 修订记录

修订日期 | 修订版本 | 修改描述 | 作者
2019.01.14 | V2.0.0 | 对接 IoT Hub 的鉴权、MQTT/Coap 通信指令 | Francisgan
2019.02.18 | V3.0.0 | 修改命令相应格式，增加设备设置类命令， 增加证书的写入、校验、删除命令，增加 OTA 升级指令 | Yougaliu
2019.02.18 | V3.0.1 | 修订错误码相关 | Francisgan
2019.02.21 | V3.0.2 | 根据反馈意见修改 | Yougaliu
2019.04.23 | V3.1.0 | 修改部分细节 | Spikelin
2019.06.11 | V3.1.1 | 增加产品级密钥、动态注册、获取模组信息 及清除设备信息等命令 | Spikelin
2019.06.14 | V3.1.2 | 更新网络注册命令及对应 URC | Yougaliu
2019.07.31 | V3.1.3 | 统一返回数据格式，增加相关说明和例子 | Spikelin

目录

### 1 说明

1.1 名词解释

MQTT | 一种基于轻量级代理的 Pub/Sub 模型的消息传输协议
CoAP | 一种适用于受限资源场景的应用协议
Topic | 主题,Pub/Sub 模型中消息的通信媒介,Pub/Sub 必 须要有主题,只有当订阅了某个主题后,才能收到相应主 题数据信息,才能进行通信
Pub | 设备端的发布协议,意思是往 Topic 中发布消息
Sub | 设备端的订阅协议,意思是从 Topic 中订阅消息
URC | 全称 Unsolicited Result Code，非请求结果码，一般 为模组给 MCU 的串口返回

更多信息请参考:https://cloud.tencent.com/document/product/634/31015,以及腾讯云物联网通 信的相关文档
1.2 符号说明
1. 本文档所有语法声明中（包括测试命令、读取命令、设置命令）,所有形如”xxx”的双引号 引注信息,都是确定内容的信息
例:
发送 | AT+TCDEVINFOSET =?

返回

+ TCDEVINFOSET: “TLSMODE (0/1/2)”, “PRODUCTID”,“DEVICENAME”[,” DEVICESECRET”]

OK
”ProductId”，”DeviceName”,等,指确定的字符串”ProductId”， ”DeviceName”
2. 本文档所有语法声明中（包括测试命令、读取命令、设置命令）,所有形如<xxx>的尖角 括号引注信息,都是指变量信息
例:
发送 | AT+TCDEVINFOSET?
返回 | +TCDEVINFOSET: <tlsmode>,<productId>,<devicename>,[,<devicesecret>]
| OK
< productId >,< devicename >等,指实际的产品ID和设备名称,如” CTQS08Y5LG”，” Dev01”

3. 在表示具体的参数数据时,字符串类型的数据需要由双引号”xx”引注，数值型数据直接以 数据表示。参数数据之间需要用逗号,分隔。例：
发送 | AT+TCCERTADD=”cdev_cert.crt”,1428
返回 | OK
| > +TCCERTADD: OK

1428 表示数值型数据。”cdev_cert.crt”表示字符串型。建议用户参照示例编写程序。 可参考 AT+TCMQTTPUB 和 AT+TCMQTTSUB 关于指令执行成功和失败的示例。
4. 关于返回结果的空格，模组可根据其 AT 指令惯例来确定是否需要空格，一般建议在返 回结果的冒号和数据信息之间只有一个空格，其他都没有空格。
发送 | AT+TCMQTTSUB="S3EUVBRJLB/demo-device/event",0
返回 | OK +TCMQTTSUB: FAIL,-108
5. 每条 AT 指令的结束，返回数据以及上报 URC 数据的结束都应以<CR><LF>也即“\r\n” 作为结束符号。
6. 校验和（BCC）生成方法，返回十进制校验和

int CalcCheck(BYTE* Bytes, int len){
int i, result;
for (result = Bytes[0], i = 1; i < len ; i++){
| result ^= Bytes[i];
}
return result;
}

### 2 TC 网络注册、设备信息设置及模组信息命令

2.1 AT+TCREGNET (网络注册)

作用 | 模组联网（蜂窝模组和 WIFI 模组统一）
测试命令 返回 | AT+TCREGNET=? +TCDEVINFO: “MODULE_TYPE (0/1)”,”ACTION(0/1)”,“STATE(0/1)”, “IP”, [,”SSID” ,”PSW”（WIFI_MODULE）] [,”CSQ” （CELLULAR_MODULE）] OK
读取命令 返回 | AT+ TCREGNET? +TCREGNET: <module_type>,<state>,<ip>[,<ssid>,<pw>] [,<csq>] OK 返回说明： <modue_type>: 0：蜂窝模组 1：wifi 模组 <state>：联网/入网状态，0：未联网/未注册 1：已联网/已注册 <ip>：模组获取到的 IP

[<ssid>,<pw>]:wifi 模组必选，返回热点名称及密码 [<csq>]:蜂窝模组必选，返回信号质量
设置命令 返回 | AT+TCREGNET=<module_type>,<action>[,<ssid>,<pw>][,<apn>] OK 或者 +CME ERROR: <err> 如果输入合法,首先返回 OK,接下来返回设备信息设置成功与否 +TCREGNET: <module_type>,<STATE>[,<errcode>]
参数说明 | < module_type >: 模组类型，数值型，0：蜂窝模组，1：wifi 模组。用于 区分命令参数 <action>: 0 断开网络 1 连接网络 [< ssid >]: wifi 模组为必填项,字符串类型,热点名字，最长 48 字节，无中文 [< pw>]: wifi 模组为必填项,字符串类型,热点密码，最长 48 字节，无中文 [<apn>]:蜂窝模组为必选型，字符串类型，运营商标识符。
| AT+TCREGNET=0,1,”CMNET” OK +TCREGNET: 0,NET_OK AT+TCREGNET? +TCREGNET: 0,1,”123.10.2.10”,23 OK | 蜂窝模 组激活 联网成 功 查询状 态已联 网，获取 IP 为 123.10.2 .10，CSQ 为 23
| AT+TCREGNET=0,0 OK +TCREGNET: 0,NET_CLOSE AT+TCREGNET? +TCREGNET: 0,0,,23 OK | 蜂窝模 组断开 拨号成 功 查询状 态为未 联网，未 获取 IP， CSQ 为 23

示例

AT+TCREGNET=0,1,”CMNET” OK +TCREGNET: 0,NET_FAIL,202 | 蜂窝模 组激活 联网失 败，原因 为 202 超时
AT+TCREGNET=0,1,”CMNET” OK +TCREGNET: 0,OK +TCREGNET: 0,NET_CLOSE | 蜂窝模 组拨号 成功后， 网络断 开
AT+TCREGNET=1,1,”TP-LINK-E10”,”12345678” OK +TCREGNET: 1,NET_OK | WIFI 模 组联网 成功
AT+TCREGNET=1,0 OK +TCREGNET: 1,NET_CLOSE | WIFI 模 组联网 断开成 功

2.2 AT+TCDEVINFOSET (平台设备信息设置)

作用 | 设置腾讯云物联网平台创建的产品及设备信息
测试命令 返回 | AT+TCDEVINFOSET=? +TCDEVINFO:“TLSMODE (0/1/2)”, “PRODUCTID”, “ DEVICENAME ” [,” DEVICESECRET”(TLSMODE=0/1)] or[,”CERTNAME”(TLSMODE=2)] 设备信息数据会保存到 FLASH，掉电不丢失 OK
读取命令 返回 | AT+TCDEVINFOSET? +TCDEVINFOSET:<tlsmode>,<productId>,<devicename>,[,<devicesec ret_checksum>] or [,<certname>] OK 注意：<tlsmode>=0/1，不返回 devicesecret 的字符串内容，只返回 devicesecret 字符串的校验和(BCC)
设置命令 返回 | AT+TCDEVINFOSET=<tlsmode>,<productId>,<devicename>[,< devicesecret>][,<certname>] OK

或者
+CME ERROR: <err>

如果模组已经连接腾讯云 MQTT 服务器，则返回错误，用户需要先发送断 开连接命令（AT+TCMQTTDISCONN）才能执行该命令。
如果模组处于 OTA 状态中，则不支持该设置命令，会返回错误。

如果输入合法,首先返回 OK,接下来返回设备信息设置成功与否 +TCDEVINFOSET: OK 设置成功
+TCDEVINFOSET: FAIL,<err_code> 设置失败
参数说明 | < tlsmode >: 接入方式，必填项，0：直连模式，1：TLS 密钥方式 2：TLS 证书方式，数值类型 < productId >: 产品 id, 必填项,字符串类型,最大长度 10 < devicename >: 设备名称,必填项,字符串类型，最大长度 48 [<deviceSecret>]: 设备密钥,字符串类型。接入方式 0/1 为必填项。 [<certname>]: 选择鉴权使用的公钥证书名，字符串类型。接入方式 2 为 必填项。方式 2 需前置命令 AT+TCCERTADD，该命令校验证书是否存在及 合法。
示例 | AT+TCDEVINFOSET=1,”CTQS08Y5LG”,”Dev01”,”ZHNkIGRzZCA =” OK +TCDEVINFOSET: OK | 设置 成 功

2.3 AT+TCCERTADD (证书添加)

作用 | 添加证书或私钥
测试命令 返回 | AT+TCCERTADD=? AT+TCCERTADD:“CERT_NAME”, CERT_SIZE (1-4096) OK
读取命令 返回 | AT+TCCERTADD? +TCCERTADD: <cert_name>,<cert_size> +TCCERTADD: <private_key_name>,<privatekey_size> ： （list of cert pair） OK
设置命令 返回 | AT+TCCERTADD=<cert_name>,<cert_size> OK > 或者 +CME ERROR: <err>

如果输入合法,首先返回 OK,接下来返回 >,待收取<cert_size>长度数据或 者收取到 Ctr+Z，结束接收，并保存证书，返回证书接收结果 +TCCERTADD: OK 添加成功
+TCCERTADD: FAIL,<err_code> 添加失败
参数说明 | <Cert_name>: 证书名称，必填项，字符串类型 < Cert_size >:证书大小，单位字节，必填项, 数值型 注意：在平台创建设备后会生成公私钥对，公私钥对写入的时候文件名需 一致，后缀名区分（公钥.crt 私钥.key）。
示例 | AT+TCCERTADD=”cdev_cert.crt”,1428 OK > +TCCERTADD: OK | 添加成功

2.4 AT+TCCERTCHECK (证书校验)

作用 | 校验证书或私钥
测试命令 返回 | AT+TCCERTCHECK=? +TCCERTCHECK:“Cert_name” OK
读取命令 返回 | AT+TCCERTCHECK? +TCCERTCHECK: <Cert_name> +TCCERTCHECK: <Pivate_key_name> ： （list of cert） OK
设置命令 返回 | AT+TCCERTCHECK=<cert_name> OK 或者 +CME ERROR: <err> 如果输入合法,首先返回 OK,接下来返回证书校验成功与否 +TCCERTCHECK: OK 设置成功 +TCCERTCHECK: FAIL,<err_code> 设置失败
参数说明 | < cert_name >: 待校验的证书或私钥名，必填项，字符串类型
示例 | AT+TCCERTCHECK =”cdev_cert.crt” | 校验成功

OK
+TCCERTCHECK: OK

2.5 AT+TCCERTDEL (证书删除)

作用 | 删除证书或私钥
测试命令 返回 | AT+TCCERTDEL=? +TCCERTDEL: “Cert_name” OK
读取命令 返回 | AT+TCCERTDEL? +TCCERTDEL: <Cert_name> +TCCERTDEL: <Pivate_key_name> ： （list of cert） OK
设置命令 返回 | AT+TCCERTDEL=<cert_name> OK 或者 +CME ERROR: <err> 如果输入合法,首先返回 OK,接下来返回证书删除成功与否 +TCCERTDEL: OK 删除成功 +TCCERTDEL: FAIL,<err_code> 删除失败
参数说明 | < cert_name >: 待校验的证书或私钥名，必填项，字符串类型
示例 | AT+TCCERTDEL =”cdev_cert.crt” OK +TCCERTDEL: OK | 删除成功

2.6 AT+TCPRDINFOSET (平台产品信息设置)

作用 | 设置腾讯云物联网平台创建的产品信息，适用于产品级密钥场景
测试命令 返回 | AT+TCPRDINFOSET=? +TCPRDINFOSET:”TLS_MODE(0/1/2)”,”PRODUCT_ID”,”PRODUCT_SECRET_ BCC”,” DEVICE_NAME” OK
读取命令 | AT+TCPRDINFOSET?

返回

+TCPRDINFOSET:<tls_mode>,<product_ID>,<product_secret_checksu m>,<device_name>

OK
设置命令 返回 | AT+TCPRDINFOSET=<tls_mode>,<product_ID>,<product_secret>,<devic e_name> OK 或者 +CME ERROR: <err> 如果模组已经连接腾讯云 MQTT 服务器，则返回错误，用户需要先发送断 开连接命令（AT+TCMQTTDISCONN）才能执行该命令。 如果模组处于 OTA 状态中，则不支持该设置命令，会返回错误。 如果输入合法,首先返回 OK,接下来返回设备信息设置成功与否 +TCPRDINFOSET: OK 设置成功，产品数据会保存到 FLASH，掉电不丢失 +TCPRDINFOSET: FAIL,<err_code> 设置失败
参数说明 | <tls_mode>: 接入方式，必填项，0：直连模式，1：TLS 密钥方式 2：TLS 证书方式，数值类型 <product_ID>: 产品 ID，必填项，字符串类型，最大长度 10 <product_secret>: 产品密钥，必填项，字符串类型，最大长度 32。 <device_name>: 设备名称，必填项，字符串类型，最大长度 48。
示例 | AT+TCPRDINFOSET=1,”CTQS08Y5LG”,”ZHNkIGRzZCA=”,”Dev0 1” OK +TCPRDINFOSET: OK | 设置成 功

2.7 AT+TCDEVREG(执行设备动态注册)

作用 | 采用产品级密钥场景下，执行设备动态注册并获取设备信息。
测试命令 返回 | AT+TCDEVREG=? OK
执行命令 返回 | AT+TCDEVREG OK 或者 +CME ERROR: <err> 如果模组已经连接腾讯云 MQTT 服务器，则返回错误，用户需要先发送断 开连接命令（AT+TCMQTTDISCONN）才能执行该命令。 如果模组处于 OTA 状态中，不支持该设置命令，会返回错误。 如果执行状态合法,首先返回 OK,接下来返回设备信息注册成功与否

+TCDEVREG: OK 动态注册成功，设备密钥信息会保存到 FLASH +TCDEVREG: FAIL,<err_code> 动态注册失败，返回错误码，具体参见本文 档错误码章节
示例 | AT+TCDEVREG OK +TCDEVREG: OK
说明 | 使用产品级密钥场景下执行动态注册的逻辑说明： 1. 如果模组上面没有完整的设备信息，即设备未注册未激活，则正常注册， 返回成功/失败。 2. 模组上已存在一个设备 A，且是已注册未激活状态，如果用户使用 AT+TCPRDINFOSET 提供的设备信息也是 A，则正常注册，云端会重新分 配 PSK 或证书，返回成功/失败。 3. 模组上已存在一个设备 A，且是已注册已激活状态，如果用户使用 AT+TCPRDINFOSET 提供的设备信息也是 A，则会注册失败，AT 命令返 回错误，用户需要更换设备信息或在云端将设备重置。 4. 模组已存在一个设备 A 的信息，如果用户使用 AT+TCPRDINFOSET 提 供了一个新的设备 B 的信息，则会使用新的设备 B 的信息去注册，注册成 功则覆盖原来设备 A 的信息，注册失败则原有的设备 A 信息不变。 5. 正常情况下，设备动态注册仅需执行一次，执行成功后，设备密钥信息 已 经 保 存 在 模 组 FLASH 中 ， 后 续 上 电 初 始 化 时 可通过 指令 AT+TCDEVINFOSET?查询是否存在正确的设备信息并正常连接腾讯云 MQTT 服务

2.8 AT+TCMODULE(模组信息读取)

作用 | 获取模组相关的硬件及软件信息。
执行命令 返回 | AT+TCMODULE Module HW name: 模组硬件信息，必选项 Module FW version: 模组固件信息，必选项 Module Mac addr/Module IMEI: WiFi 模组 mac 地址或蜂窝模组 IMEI 号 前面三项为必须提供项，且名称须与文档保持一致 后面可添加选填项，如模组需要上报的其他定制化信息如固件编译时间等 等 OK
示例 | AT+TCMODULE Module HW name: ESP-WROOM-02D Module FW version: QCloud_AT_v1.0.0_ESP_WiFi Module Mac addr: 3c:71:bf:33:af:fd Module FW compiled time: Jun 11 2019 20:30:10 Module Flash size: 2MB OK

2.9 AT+TCRESTORE(清除模组设备信息)

作用 | 清除模组 FLASH 上保存的腾讯云设备信息。
测试命令 返回 | AT+TCRESTORE=? OK
执行命令 返回 | AT+TCRESTORE OK 或者 +CME ERROR: <err> 如果模组已经连接腾讯云 MQTT 服务器，则返回错误，用户需要先发送断 开连接命令（AT+TCMQTTDISCONN）才能执行该命令。 如果模组处于 OTA 状态中，则不支持该设置命令，会返回错误。 如果状态允许，则返回 OK，然后清除模组上面存储的腾讯云相关设备及产 品信息，以及缓存的 OTA 固件信息，并重启模组。 注意该命令不会清除模组信息（即通过 AT+TCMODULE 可以读取的信息）
示例 | AT+TCRESTORE OK

### 3 TC MQTT 命令

3.1 AT+TCMQTTCONN(配置 MQTT 连接参数)
作用 | 配置 MQTT 连接参数,包括客户端和服务器的心跳间隔,会话控制,并连接腾 讯云端服务器
测试命令 返回 | AT+TCMQTTCONN=? +TCMQTTCONN:<TLSMODE_SELECTED>,<CMDTIMEOUT_VALUE>, <KEEPALIVE>(max 690s),<CLEAN_SESSION>(0/1) ,<RECONNECT>(0/1) OK
读取命令 | AT+TCMQTTCONN? +TCMQTTCONN:<tlsmode>,<cmdtimeout>,<keepalive>,<clean_se ssion>,<reconnect> OK 注意: KEEPALIVE 的默认值为 240, CLEAN_SESSION 的默认值为 1

返回

设置命令 | AT+TCMQTTCONN=<tlsmode>,<cmdtimeout>,<keepalive>,<clean_sessi on>,<reconnect>
返回 | OK

或者
+CME ERR: <err>

如果模组已经连接腾讯云 MQTT 服务器，则返回错误，用户需要先发送断 开连接命令（AT+TCMQTTDISCONN）才能再次连接。
如果模组处于 OTA 状态中，则不支持该设置命令，返回错误。

如果输入合法,首先返回 OK,然后返回连接成功与否
+TCMQTTCONN: OK 连接成功
+TCMQTTCONN: FAIL,<err_code> 连接失败
参数说明 | <tlsmode>：接入方式，必填项，0：直连模式，1：TLS 密钥方式 2：TLS 证书方式，整型。AT+TCDEVINFOSET 命令<tlsmode> 为 0 或 2 时，该值须对应为 0 或 2。AT+TCDEVINFOSET 命令 <tlsmode>为 1 时，该值可为 0 或 1 <cmdtimeout>：命令超时时间，整型，MQTT 连接、发布、订阅的超时时 间，单位 ms，建议设置为 5000，可以根据网络环境调整该 值。 <keepalive > 心跳间隔，必填项，整型，范围 60-690(秒) <clean_session > 是否清除会话，必填项，整型，0：不清除， 1：清除 <reconnect>:MQTT 断连后是否重连，必填项，整型，0：不自动重连 1： 自动重连 注意：该命令前置依赖 AT+TCDEVINFOSET 命令
示例 | AT+TCMQTTCONN=1,5000,240,1,1 OK +TCMQTTCONN: OK

3.2 AT+TCMQTTDISCONN(断开 MQTT 连接)

作用 | 断开与腾讯云的 MQTT 连接。
测试命令 返回 | AT+TCMQTTDISCONN=? OK
执行命令 返回 | AT+TCMQTTDISCONN OK 或者 +CME ERROR: <err> 如果模组处于 OTA 状态中，则不支持该设置命令，返回错误。 注意:未连接状态下返回+CME ERROR:<err>
示例 | AT+TCMQTTDISCONN OK

3.3 AT+TCMQTTPUB(向某个 Topic 发布消息)

作用 | 向某个 Topic 发布消息
测试命令 返回 | AT+TCMQTTPUB=? +TCMQTTPUB: ”TOPIC_NAME(maxlen 128)”, ”QOS(0/1)”,”PAYLOAD (maxlen 1024)” OK
设置命令 返回 | AT+TCMQTTPUB=<topic>,<qos>,<message> OK 否则,返回 +CME ERR: <err> 如果模组尚未连接腾讯云 MQTT 服务器，则返回错误，用户需要先发送连 接命令（AT+TCMQTTCONN）才能发布消息。 如果输入合法,首先返回 OK,接下来返回消息发布成功与否。如果是 QoS1 消息，会等到收到 PUBACK 或超时失败再返回。 如果输入合法,首先返回 OK,接下来返回消息发布成功与否 +TCMQTTPUB: OK 发布成功 +TCMQTTPUB: FAIL,<err_code> 发布失败
参数说明 | <topic>:发布消息的 Topic name，字符串最大长度 128 <qos>:QoS 值,暂只支持 0,1 <message>:发布的消息体的内容，最大长度 1024
示例 | AT+TCMQTTPUB="S3EUVBRJLB/device1/get ",1,"hello world" OK +TCMQTTPUB: OK | 消息发 布成功
示例 | AT+TCMQTTPUB="S3EUVBRJLB/device1/control",1,"hello" OK +TCMQTTPUB: FAIL,202 | 消息发 布超时 失败，比 如该主 题没有 发布权 限

3.4 AT+TCMQTTPUBL(向某个 Topic 发布长消息)

作用 | 向某 Topic 发布长消息，解决 AT+TCMQTTPUB 消息体长度大于 2048 场景
测试命令 返回 | AT+TCMQTTPUBL=? +TCMQTTPUBL: ”TOPIC_NAME(maxlen128)”, ”QOS(0/1)”,”LEN(1-102 40)” OK
设置命令 返回 | AT+TCMQTTPUBL= <topic>,<qos>,<msg_length> OK > 或者 +CME ERR:<err> 如果输入合法,首先返回 OK,接下来返回 >,待收取<msg_length>长度数据 或者收取到 Ctr+Z，结束接收，并返回发送结果 +TCMQTTPUBL: OK 发布成功 +TCMQTTPUBL: FAIL,<err_code> 发布失败
参数说明 | <topic>:发布消息的 Topic name，最大字符串长度 1024 <qos>:QoS 值,暂只支持 0,1 < msg_length >:发布的消息体的长度，最大长度 10240
示例 | AT+TCMQTTPUBL="iot-ee54phlu/device1/get",1,11 > Hello,world OK +TCMQTTPUBL: OK | 消息发 布成功

3.5 AT+TCMQTTSUB(订阅 MQTT 某个 Topic)
作用 | 订阅 MQTT 某个 Topic
测试命令 返回 | AT+TCMQTTSUB=? +TCMQTTSUB:”TOPIC_NAME”,”QOS(0/1)” OK
读取命令 返回 | AT+TCMQTTSUB? OK

或者
+TCMQTTSUB: <topic>,<qos>
：
：list of sub topic
+TCMQTTSUB: <topic_n>,<qos>

OK

注意:如果有已经订阅的消息,返回已订阅的 topic 列表。
设置命令 返回 | AT+TCMQTTSUB=<topic>,<qos> OK 或者 +CME ERROR: <err> 如果模组尚未连接腾讯云 MQTT 服务器，则返回错误，用户需要先发送连 接命令（AT+TCMQTTCONN）才能订阅消息。 如果输入合法,首先返回 OK,然后返回订阅成功与否，该命令会等到收到 SUBACK 或超时失败再返回。 +TCMQTTSUB: OK 订阅成功 +TCMQTTSUB: FAIL,<err_code> 订阅失败
参数说明 | <topic>: 订阅的 Topic name,最大长度 128 <qos>: QoS 值,暂只支持 0,1
示例 | AT+TCMQTTSUB="S3EUVBRJLB/device1/control",0 OK +TCMQTTSUB: OK | 订阅主题成功
示例 | AT+TCMQTTSUB="S3EUVBRJLB/device1/event",0 OK +TCMQTTSUB: FAIL,-108 | 订阅主题失败， 比如该主题没有 订阅权限

3.6 AT+TCMQTTUNSUB(取消已经订阅的 Topic)

作用 | 取消已订阅的 Topic
测试命令 返回 | AT+TCMQTTUNSUB=? +TCMQTTUNSUB: ” TOPIC_NAME” OK
读取命令 返回 | AT+TCMQTTUNSUB? OK 或者 +TCMQTTUNSUB: <topic> OK

注意:如果有已经取消订阅的消息,返回上一次取消的 topic。
设置命令 返回 | AT+TCMQTTUNSUB=<topic> OK 或者 +CME ERROR: <err> 如果输入合法,首先返回 OK,然后返回取消订阅成功与否 +TCMQTTUNSUB: OK 取消订阅成功 +TCMQTTUNSUB: FAIL,<err_code> 取消订阅失败
参数说明 | <topic>: 取消订阅的 Topic

3.7 AT+TCMQTTSTATE(查询 MQTT 连接状态)

作用 | 查询 MQTT 连接状态
测试命令 返回 | AT+TCMQTTSTATE=? OK
读取命令 返回 | AT+TCMQTTSTATE？ +TCMQTTSTATE: <state> OK
参数说明 | <state>: MQTT 连接状态 0:MQTT 已断开 1:MQTT 已连接
示例 | AT+TCMQTTSTATE? +TCMQTTSTATE: 1 OK

### 4 模组配合腾讯云 IOT 平台实现 MCU 测 OTA 功能

4.1 AT+TCOTASET (OTA 功能使能控制及版本设置)

作用 | OTA 功能使能控制及版本设置
测试命令 返回 | AT+TCOTASET=? +TCOTASET: ”ENABLE/DISABLE”，”FW_version” OK
读取命令 返回 | AT+TCOTASET? OK +TCOTASET: <ctlstate>,<fw_ver> 或者 +CME ERROR: <err>

设置命令 返回 | AT+TCOTASET=<ctlstate>,<fw_ver> OK 或者 +CME ERROR: <err> 如果已经在 OTA 下载状态中，则返回错误。 如果输入合法,首先返回 OK,然后启动后台下载任务，并返回上报本地版本 成功与否 +TCOTASET: OK OTA 功能设置 OK +TCOTASET: FAIL,<err_code> OTA 功能设置失败
参数说明 | <ctlstate>: OTA 使能控制，布尔型，0 关闭，1 使能。enable 上报本地版 本并启动后台下载任务；disable 则取消后台下载任务 < fw_ver >: 系统当前固件版本信息，字符型，版本格式：V.R.C，譬如 1.0.0
示例 | AT+TCOTASET=1,”1.0.1” OK +TCOTASET: OK

4.2 AT+TCFWINFO (读取模组缓存的固件信息)

作用 | 读取模组缓存的固件信息
测试命令 返回 | AT+TCFWINFO=? +TCFWINFO: ”FW_VERSION”，”FW_SIZE” ，”FW_MD5”,”FW_MAX_SIZ E_OF_MODULE” OK 注意：”FW_MAX_SIZE_OF_MODULE”，用户待升级的 OTA 固件的最大字节 数，模组根据自身资源情况返回，最小必须是 128KB
读取命令 返回 | AT+TCFWINFO? OK +TCFWINFO: <fw_verion>,<fw_size>,<fw_md5>,<fw_max_size> 或者 +CME ERROR: <err> 注意：每执行一次固件信息读取，已读取的固件数据偏移位置初始化为 0。 如果已经在 OTA 下载状态中，则返回错误。
示例 | AT+TCFWINFO？ OK +TCFWINFO: "1.2.0",17300,"a2aa3c261ebfc1322edafd37edb6b183",262144

4.3 AT+TCREADFWDATA (读取模组缓存的固件数据)

作用 | 读取模组缓存的固件数据
测试命令 返回 | AT+TCREADFWDATA=? +TCREADFWINFO: ”LEN_FOR_READ” OK
设置命令 返回 | AT+TCREADFWDATA=<len> +CME ERROR: <err> 或者 +TCREADFWDATA: len,hexdata… 注意：每读一次，模组实现偏移累加，用户需要根据固件大小判断是否读 取完毕。如果 AT 返回成功，但返回的长度小于要读取的长度，则表示固 件已经读取到尽头。用户再次读取会返回错误，需要发起 AT+TCFWINFO 指令将偏移量清零，才可以重新开始读取固件。 如果正在 OTA 下载状态中，则返回错误。
参数说明 | <len>: 该次读取的固件二进制数据长度，该长度不包括结束符号\r\n，整 型数据
示例 | AT+TCREADFWDATA=512 OK +TCREADFWDATA:512,01020AF5…..

4.4 模组配合腾讯云 IOT 平台实现 MCU 测 OTA 功能流程图

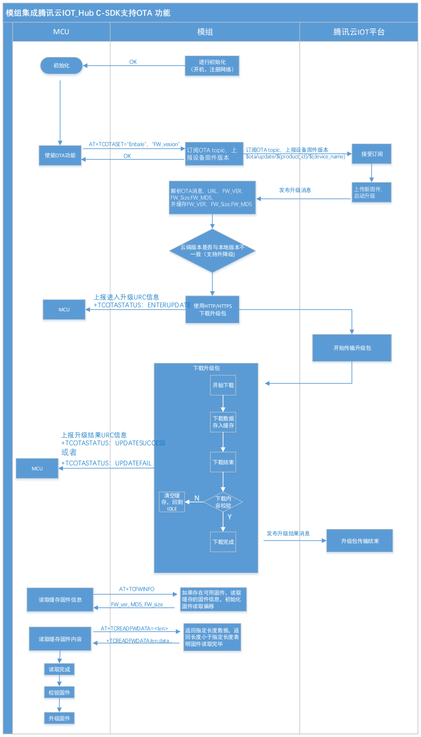
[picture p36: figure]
模组集成腾讯云IOT_Hub C-SDK支持OTA 功能; MCU; 腾讯云IOT平台; 下载升级包; 初始化; 进行初始化; （开机、注册网络）; 使能OTA功能; 订阅OTA topic，上 报设备固件版本; 接受订阅; 使用HTTP/HTTPS 下载升级包; 开始下载; 开始传输升级包; 下载数据 存入缓存; 下载结束; 下载内 容校验; 清空缓 存，回到 IDLE; 下载完成; 读取缓存固件信息; 如果存在可用固件，读取 缓存的固件信息，初始化; 固件读取偏移; 返回指定长度数据，返 回长度小于指定长度表 明固件读取完毕; 升级固件; 校验固件; 上传新固件， 启动升级; AT+TCOTASET= Enbale ， FW_vesion; 订阅OTA topic，上报设备固件版本 $ota/update/$(product_id)/$(device_name); 解析OTA消息，URL，FW_VER， FW_Size,FW_MD5, 并缓存FW_VER，FW_Size,FW_MD5; 发布升级消息; 云端版本是否与本地版本不 一致（支持升降级); 上报进入升级URC信息 +TCOTASTATUS：ENTERUPDATE; 上报升级结果URC信息 +TCOTASTATUS：UPDATESUCCESS 或者; +TCOTASTATUS：UPDATEFAIL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

## 5 URC,模组主动上报 MCU 消息

5.1 +TCMQTTRCVPUB(收到订阅的 Topic 时上报的消息)

作用 | 收到订阅的 Topic 的消息时上报给 MCU 的信息
消息格式 | +TCMQTTRCVPUB: <topic>,<message_len>,<message>
参数说明 | <topic>: 收到消息的 Topic <message_len>: 数值型，收到消息体的长度(不含””) < message>: 收到消息体的内容
示例 | +TCMQTTRCVPUB:" CTQS08Y5LG/Dev01/get ",11,"hello world"

5.2 +TCMQTTDISCON(MQTT 断开时上报的信息)

作用 | MQTT 连接被服务器断开时上报的 URC
示例 | +TCMQTTDISCON,<err code> Err code 错误码详情可以查询错误码章节

5.3 +TCMQTTRECONNECTING(MQTT 正在重连时上报的信息)

作用 | MQTT 连接与服务器断开并正在进行自动重连时候上报的 URC
示例 | + TCMQTTRECONNECTING

5.4 +TCMQTTRECONNECTED (MQTT 重连成功时上报的信息)

作用 | MQTT 连接与服务器断开后自动重连成功时上报的 URC
示例 | + TCMQTTRECONNECTED

5.5 +TCOTASTATUS (上报 OTA 状态)

作用 | OTA 状态发生变化时上报的 URC
消息格式 | +TCOTASTATUS: <state>
参数说明 | <state> ： OTA 状态， ENTERUPDATE ： 模 组 进 入 固 件 下 载 状 态 ， UPDATESUCCESS：固件下载成功（包括固件校验和缓存成功），UPDATEFAIL： 固件下载失败
示例 | + TCOTASTATUS: UPDATESUCCESS

5.6 +TCREGNET (上报网络状态变化)

作用 | 网络状态发生变化时上报的 URC
消息格式 | +TCREGNET: <module_type>,<STATE>[,<errcode>]

参数说明 | <module_type>: 模组类型，数值型，0：蜂窝模组，1：wifi 模组。用于区 分命令参数 <STATE>：当前状态，字符串类型 NET_OK 联网成功 NET_FAIL 联网失败 NET_CLOSE 网络断开，主动断开或者被动断开时上报该指令 <errcode>：错误码 参考附录
示例 | +TCREGNET: 0,NET_OK

### 6 错误码

6.1 服务端相关 err code
<err>代码 | 含义
101 | 设备连接失败 | device connect fail
110 | 设备订阅失败：无 topic 权限 | device subscribe fail: unauthorized operation
111 | 设备订阅失败：系统错误 | device subscribe fail: system error
120 | 设备退订失败：系统错误 | device unsubscribe fail: system error
130 | 设备发布消息失败：无 topic 发 布权限 | device publish message to topic fail： unauthorized operation
131 | 设备发布消息失败：publish 超过 频率限制 | device publish message to topic fail： reach max limit
132 | 设备发布消息失败：payload 超 过长度限制 | device publish message to topic fail： payload too long
执行错误码 | 含义
-3, | 远程主机关闭连接 | QCLOUD_ERR_HTTP_CLOSED
-4, | HTTP 未知错误 | QCLOUD_ERR_HTTP
-5, | 协议错误 | QCLOUD_ERR_HTTP_PRTCL
-6, | 域名解析失败 | QCLOUD_ERR_HTTP_UNRESOLVED_DN S
-7, | URL 解析失败 | QCLOUD_ERR_HTTP_PARSE
-8, | HTTP 连接失败 | QCLOUD_ERR_HTTP_CONN
-9, | HTTP 鉴权问题 | QCLOUD_ERR_HTTP_AUTH
-10, | HTTP 404 | QCLOUD_ERR_HTTP_NOT_FOUND
-11, | HTTP 超时 | QCLOUD_ERR_HTTP_TIMEOUT
-102 | 表示往等待 ACK 列表中添加 元素失败 | QCLOUD_ERR_MQTT_PUSH_TO_LIST_ FAILED
-103 | 表示未与 MQTT 服务器建立连 接或已经断开连接 | QCLOUD_ERR_MQTT_NO_CONN
-104 | 表示 MQTT 相关的未知错误 | QCLOUD_ERR_MQTT_UNKNOWN

-105 | 表示正在与 MQTT 服务重新建 立连接 | QCLOUD_ERR_MQTT_ATTEMPTING_R ECONNECT
-106 | 表示重连已经超时 | QCLOUD_ERR_MQTT_RECONNECT_TI MEOUT
-107 | 表示超过可订阅的主题数 | QCLOUD_ERR_MQTT_MAX_SUBSCRIP TIONS
-108 | 表示订阅主题失败, 即服务器 拒绝 | QCLOUD_ERR_MQTT_SUB
-109 | 表示无 MQTT 相关报文可以读 取 | QCLOUD_ERR_MQTT_NOTHING_TO_ READ
-110 | 表示读取的 MQTT 报文有问题 | QCLOUD_ERR_MQTT_PACKET_READ
-111 | 表示 MQTT 相关操作请求超时 | QCLOUD_ERR_MQTT_REQUEST_TIME OUT
-112 | 表示客户端 MQTT 连接未知错 误 | QCLOUD_ERR_MQTT_CONNACK_UN KNOWN
-113 | 表示客户端 MQTT 版本错误 | QCLOUD_ERR_MQTT_CONANCK_UN ACCEPTABLE_PROTOCOL_VERSION
-114 | 表示客户端标识符错误 | QCLOUD_ERR_MQTT_CONNACK_IDE NTIFIER_REJECTED
-115 | 表示服务器不可用 | QCLOUD_ERR_MQTT_CONNACK_SER VER_UNAVAILABLE
-116 | 表示客户端连接参数中的 username 或 password 错误 | QCLOUD_ERR_MQTT_CONNACK_BA D_USERDATA
-117 | 表示客户端连接认证失败 | QCLOUD_ERR_MQTT_CONNACK_NO T_AUTHORIZED
-118 | 表示收到的消息无效 | QCLOUD_ERR_RX_MESSAGE_INVAL
-119 | 表示消息接收缓冲区的长度小 于消息的长度 | QCLOUD_ERR_BUF_TOO_SHORT
-120 | 表示该 QOS 级别不支持 | QCLOUD_ERR_MQTT_QOS_NOT_SUP PORT
-132 | 表示 JSON 解析错误 | QCLOUD_ERR_JSON_PARSE
-133 | 表示 JSON 文档会被截断 | QCLOUD_ERR_JSON_BUFFER_TRUNC ATED
-134 | 表示存储 JSON 文档的缓冲区 太小 | QCLOUD_ERR_JSON_BUFFER_TOO_S MALL
-135 | 表示 JSON 文档生成错误 | QCLOUD_ERR_JSON
-136 | 表示超过 JSON 文档中的最大 Token 数 | QCLOUD_ERR_MAX_JSON_TOKEN
-137 | 表示超过同时最大的文档请求 | QCLOUD_ERR_MAX_APPENDING_RE QUEST
-138 | 表示超过规定最大的topic长度 | QCLOUD_ERR_MAX_TOPIC_LENGTH

-601 | 表示 TCP 连接建立套接字失败 | QCLOUD_ERR_TCP_SOCKET_FAILED
-602 | 表示无法通过主机名获取 IP 地 址 | QCLOUD_ERR_TCP_UNKNOWN_HOS T
-603 | 表示建立 TCP 连接失败 | QCLOUD_ERR_TCP_CONNECT
-604 | 表示 TCP 读超时 | QCLOUD_ERR_TCP_READ_TIMEOUT
-605 | 表示 TCP 写超时 | QCLOUD_ERR_TCP_WRITE_TIMEOUT
-606 | 表示 TCP 读错误 | QCLOUD_ERR_TCP_READ_FAIL
-607 | 表示 TCP 写错误 | QCLOUD_ERR_TCP_WRITE_FAIL
-608 | 表示 TCP 对端关闭了连接 | QCLOUD_ERR_TCP_PEER_SHUTDOW N
-609 | 表示底层没有数据可以读取 | QCLOUD_ERR_TCP_NOTHING_TO_RE AD
-701 | 表示 SSL 初始化失败 | QCLOUD_ERR_SSL_INIT
-702 | 表示 SSL 证书相关问题 | QCLOUD_ERR_SSL_CERT
-703 | 表示 SSL 连接失败 | QCLOUD_ERR_SSL_CONNECT
-704 | 表示 SSL 连接超时 | QCLOUD_ERR_SSL_CONNECT_TIMEO UT
-705 | 表示 SSL 写超时 | QCLOUD_ERR_SSL_WRITE_TIMEOUT
-706 | 表示 SSL 写错误 | QCLOUD_ERR_SSL_WRITE
-707 | 表示 SSL 读超时 | QCLOUD_ERR_SSL_READ_TIMEOUT
-708 | 表示 SSL 读错误 | QCLOUD_ERR_SSL_READ
-709 | 表示底层没有数据可以读取 | QCLOUD_ERR_SSL_NOTHING_TO_RE AD

6.2 CME ERROR 列表扩展
<err>代码 | 含义
200 | Previous command is not complete
201 | msg packet over size
202 | command timeout
203 | check failed
204 | Parameter invalid
205 | No valid firmware
206 | Memory allocation error
207 | Flash access error
208 | State error or not ready. E.g: pub msg when MQTT not connected
209 | Command execution error

6.3 设备动态注册错误码

错误码 | 内部字段 | 说明
1000 | ErrorCode_SDK_InternalError | 内部错误

错误码 | 内部字段 | 说明
1004 | ErrorCode_SDK_ProductNotExists | 产品不存在
1006 | ErrorCode_SDK_InvalidParam | 参数错误
1010 | ErrorCode_SDK_CheckSecretError | 验签失败
1011 | ErrorCode_SDK_NotSupportRegister | 产品不支持动态注册
1012 | ErrorCode_SDK_ExceedRegisterTimes | 超过设备最大注册次数
1020 | ErrorCode_SDK_NoSuchDevice | 预创建注册模式未定义设备
1021 | ErrorCode_SDK_DeviceHasRegisted | 设备已注册
1031 | ErrorCode_SDK_ExceedRegisterLimits | 设备超过设定最大自动创建注册数量

### 7 应用说明

7.1 密钥认证方式连接 TENCENT MQTT 服务器
语法 | 说明
AT+TCDEVINFOSET=1,"CTQS08Y5LG","device1"," ZHNkIGRzZCA=" OK +TCDEVINFOSET: OK | 设置设备信息
AT+TCMQTTCONN=1,5000,240,1,1 OK +TCMQTTCONN: OK | TLS 密钥方式，超时时间设置为 5000ms ， 心 跳 间 隔 为 240s,clean session 为 1,使能自 动重连，并连接 MQTT 服务器

7.2 证书认证方式连接 TENCENT MQTT 服务器
语法 | 说明
AT+TCCERTADD=”general_cdev1_cert.crt”,1216 OK > +TCCERTADD: OK AT+TCCERTADD=”general_cdev1_private.key”,1704 OK > +TCCERTADD: OK AT+TCDEVINFOSET=2,"MND067I4BM","dev_g1",” general_cdev1_cert.crt” | 设置设备证书信息

OK + TCDEVINFOSET: OK

AT+TCMQTTCONN = 2,5000,240,1,1 OK +TCMQTTCONN: OK | TLS 证书方式，超时时间设置为 5000ms ， 心 跳 间 隔 为 240s,clean session 为 1,使能自 动重连，并连接 MQTT 服务器

7.3 订阅消息
语法 | 说明
AT+TCMQTTSUB="S3EUVBRJLB/device1/data",0 OK +TCMQTTSUB: OK | 订阅消息

7.4 发布消息
语法 | 说明
AT+TCMQTTPUB="S3EUVBRJLB/demo-device/data",0, "hello world" OK +TCMQTTPUB: OK +TCMQTTRCVPUB:"S3EUVBRJLB/demo-device/data", 11,"hello world" | 发布消息，如果已经成功订阅 过该主题，则设备会收到自己 发布的消息，并通过 URC 自动 上报

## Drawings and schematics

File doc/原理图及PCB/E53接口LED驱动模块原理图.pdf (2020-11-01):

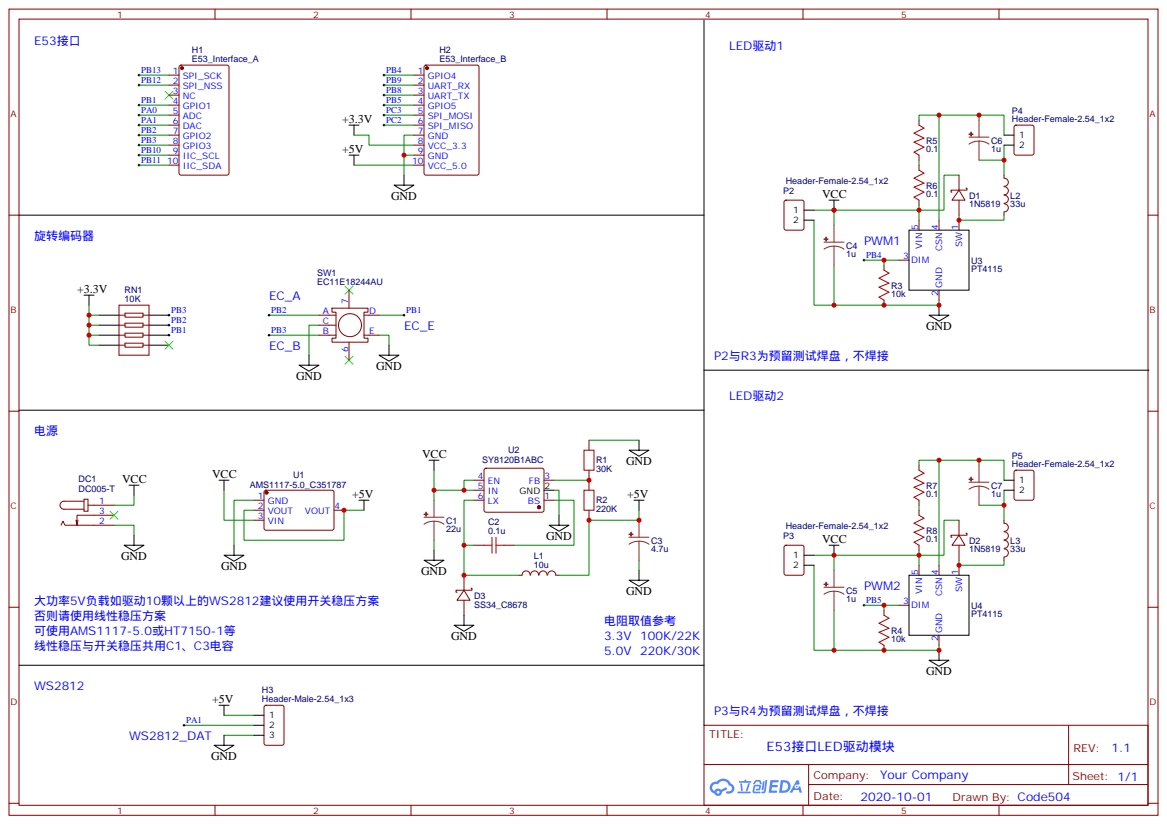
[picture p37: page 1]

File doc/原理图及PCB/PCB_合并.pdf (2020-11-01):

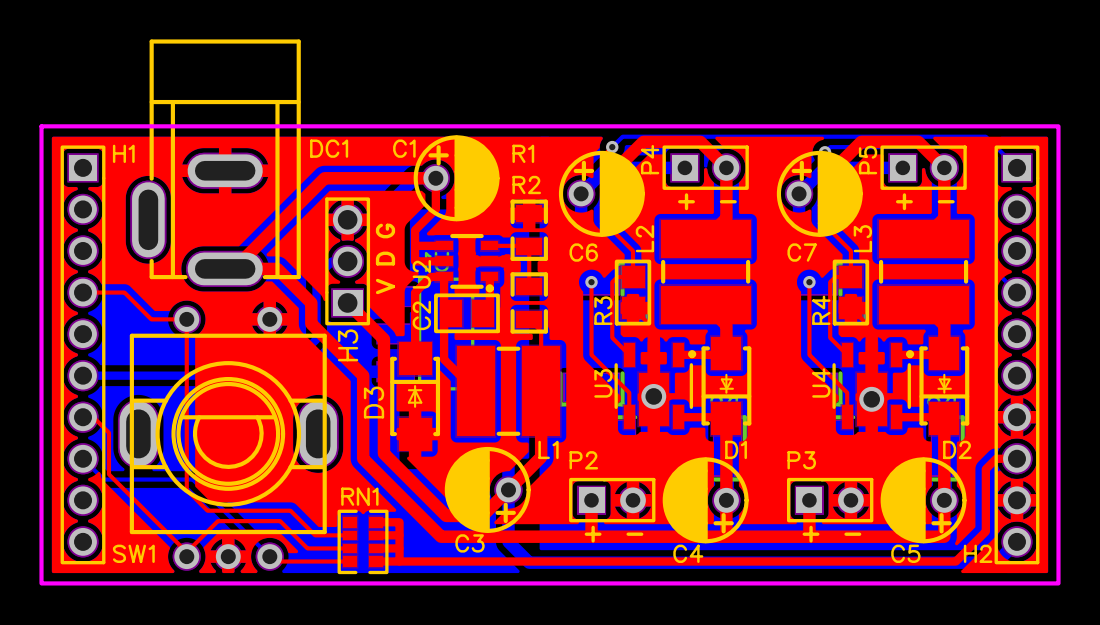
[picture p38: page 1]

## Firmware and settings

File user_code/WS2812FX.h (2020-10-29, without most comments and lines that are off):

#define WS2812FX_h
#include "ws2812_driver.h"
#include <stdint.h>
#include <stdbool.h>
#define DEFAULT_BRIGHTNESS (uint8_t)50
#define DEFAULT_MODE       (uint8_t)0
#define DEFAULT_SPEED      (uint16_t)1000
#define DEFAULT_COLOR      (uint32_t)0xFF0000
#define DEFAULT_COLORS     { RED, GREEN, BLUE }
#define COLORS(...)        (const uint32_t[]){__VA_ARGS__}
#if defined(ESP8266) || defined(ESP32)
#define SPEED_MIN (uint16_t)2
#else
#define SPEED_MIN (uint16_t)10
#endif
#define SPEED_MAX (uint16_t)65535
#define BRIGHTNESS_MIN (uint8_t)0
#define BRIGHTNESS_MAX (uint8_t)255
#define MAX_NUM_SEGMENTS         10
#define MAX_NUM_ACTIVE_SEGMENTS  10
#define INACTIVE_SEGMENT        255
#define MAX_NUM_COLORS            3
#define MAX_CUSTOM_MODES          8
#define RED        (uint32_t)0xFF0000
#define GREEN      (uint32_t)0x00FF00
#define BLUE       (uint32_t)0x0000FF
#define WHITE      (uint32_t)0xFFFFFF
#define BLACK      (uint32_t)0x000000
#define YELLOW     (uint32_t)0xFFFF00
#define CYAN       (uint32_t)0x00FFFF
#define MAGENTA    (uint32_t)0xFF00FF
#define PURPLE     (uint32_t)0x400080
#define ORANGE     (uint32_t)0xFF3000
#define PINK       (uint32_t)0xFF1493
#define GRAY       (uint32_t)0x101010
#define ULTRAWHITE (uint32_t)0xFFFFFFFF
#define DIM(c)     (uint32_t)((c >> 2) & 0x3f3f3f3f) // color at 25% intensity
#define DARK(c)    (uint32_t)((c >> 4) & 0x0f0f0f0f) // color at  6% intensity
#define NO_OPTIONS   (uint8_t)0x00
#define REVERSE      (uint8_t)0x80
#define IS_REVERSE   ((_seg->options & REVERSE) == REVERSE)
#define FADE_XFAST   (uint8_t)0x10
#define FADE_FAST    (uint8_t)0x20
#define FADE_MEDIUM  (uint8_t)0x30
#define FADE_SLOW    (uint8_t)0x40
#define FADE_XSLOW   (uint8_t)0x50
#define FADE_XXSLOW  (uint8_t)0x60
#define FADE_GLACIAL (uint8_t)0x70
#define FADE_RATE    ((_seg->options >> 4) & 7)
#define GAMMA        (uint8_t)0x08
#define IS_GAMMA     ((_seg->options & GAMMA) == GAMMA)
#define SIZE_SMALL   (uint8_t)0x00
#define SIZE_MEDIUM  (uint8_t)0x02
#define SIZE_LARGE   (uint8_t)0x04
#define SIZE_XLARGE  (uint8_t)0x06
#define SIZE_OPTION  ((_seg->options >> 1) & 3)
#define FRAME           (uint8_t)0x80
#define SET_FRAME       (_seg_rt->aux_param2 |=  FRAME)
#define CLR_FRAME       (_seg_rt->aux_param2 &= ~FRAME)
#define CYCLE           (uint8_t)0x40
#define SET_CYCLE       (_seg_rt->aux_param2 |=  CYCLE)
#define CLR_CYCLE       (_seg_rt->aux_param2 &= ~CYCLE)
#define CLR_FRAME_CYCLE (_seg_rt->aux_param2 &= ~(FRAME | CYCLE))
#define MODE_COUNT (sizeof(_names)/sizeof(_names[0]))
#define FX_MODE_STATIC                   0
#define FX_MODE_BLINK                    1
#define FX_MODE_BREATH                   2
#define FX_MODE_COLOR_WIPE               3
#define FX_MODE_COLOR_WIPE_INV           4
#define FX_MODE_COLOR_WIPE_REV           5
#define FX_MODE_COLOR_WIPE_REV_INV       6
#define FX_MODE_COLOR_WIPE_RANDOM        7
#define FX_MODE_RANDOM_COLOR             8
#define FX_MODE_SINGLE_DYNAMIC           9
#define FX_MODE_MULTI_DYNAMIC           10
#define FX_MODE_RAINBOW                 11
#define FX_MODE_RAINBOW_CYCLE           12
#define FX_MODE_SCAN                    13
#define FX_MODE_DUAL_SCAN               14
#define FX_MODE_FADE                    15
#define FX_MODE_THEATER_CHASE           16
#define FX_MODE_THEATER_CHASE_RAINBOW   17
#define FX_MODE_RUNNING_LIGHTS          18
#define FX_MODE_TWINKLE                 19
#define FX_MODE_TWINKLE_RANDOM          20
#define FX_MODE_TWINKLE_FADE            21
#define FX_MODE_TWINKLE_FADE_RANDOM     22
#define FX_MODE_SPARKLE                 23
#define FX_MODE_FLASH_SPARKLE           24
#define FX_MODE_HYPER_SPARKLE           25
#define FX_MODE_STROBE                  26
#define FX_MODE_STROBE_RAINBOW          27
#define FX_MODE_MULTI_STROBE            28
#define FX_MODE_BLINK_RAINBOW           29
#define FX_MODE_CHASE_WHITE             30
#define FX_MODE_CHASE_COLOR             31
#define FX_MODE_CHASE_RANDOM            32
#define FX_MODE_CHASE_RAINBOW           33
#define FX_MODE_CHASE_FLASH             34
#define FX_MODE_CHASE_FLASH_RANDOM      35
#define FX_MODE_CHASE_RAINBOW_WHITE     36
#define FX_MODE_CHASE_BLACKOUT          37
#define FX_MODE_CHASE_BLACKOUT_RAINBOW  38
#define FX_MODE_COLOR_SWEEP_RANDOM      39
#define FX_MODE_RUNNING_COLOR           40
#define FX_MODE_RUNNING_RED_BLUE        41
#define FX_MODE_RUNNING_RANDOM          42
#define FX_MODE_LARSON_SCANNER          43
#define FX_MODE_COMET                   44
#define FX_MODE_FIREWORKS               45
#define FX_MODE_FIREWORKS_RANDOM        46
#define FX_MODE_MERRY_CHRISTMAS         47
#define FX_MODE_FIRE_FLICKER            48
#define FX_MODE_FIRE_FLICKER_SOFT       49
#define FX_MODE_FIRE_FLICKER_INTENSE    50
#define FX_MODE_CIRCUS_COMBUSTUS        51
#define FX_MODE_HALLOWEEN               52
#define FX_MODE_BICOLOR_CHASE           53
#define FX_MODE_TRICOLOR_CHASE          54
#define FX_MODE_CUSTOM                  55  // keep this for backward compatiblity
#define FX_MODE_CUSTOM_0                55  // custom modes need to go at the end
#define FX_MODE_CUSTOM_1                56
#define FX_MODE_CUSTOM_2                57
#define FX_MODE_CUSTOM_3                58
#define FX_MODE_CUSTOM_4                59
#define FX_MODE_CUSTOM_5                60
#define FX_MODE_CUSTOM_6                61
#define FX_MODE_CUSTOM_7                62
static const char* _names[] =
{
"Static",
"Blink",
"Breath",
"Color Wipe",
"Color Wipe Inverse",
"Color Wipe Reverse",
"Color Wipe Reverse Inverse",
"Color Wipe Random",
"Random Color",
"Single Dynamic",
"Multi Dynamic",
"Rainbow",
"Rainbow Cycle",
"Scan",
"Dual Scan",
"Fade",
"Theater Chase",
"Theater Chase Rainbow",
"Running Lights",
"Twinkle",
"Twinkle Random",
"Twinkle Fade",
"Twinkle Fade Random",
"Sparkle",
"Flash Sparkle",
"Hyper Sparkle",
"Strobe",
"Strobe Rainbow",
"Multi Strobe",
"Blink Rainbow",
"Chase White",
"Chase Color",
"Chase Random",
"Chase Rainbow",
"Chase Flash",
"Chase Flash Random",
"Chase Rainbow White",
"Chase Blackout",
"Chase Blackout Rainbow",
"Color Sweep Random",
"Running Color",
"Running Red Blue",
"Running Random",
"Larson Scanner",
"Comet",
"Fireworks",
"Fireworks Random",
"Merry Christmas",
"Fire Flicker",
"Fire Flicker (soft)",
"Fire Flicker (intense)",
"Circus Combustus",
"Halloween",
"Bicolor Chase",
"Tricolor Chase",
"Custom 0", // custom modes need to go at the end
"Custom 1",
"Custom 2",
"Custom 3",
"Custom 4",
"Custom 5",
"Custom 6",
"Custom 7",
};
	typedef uint16_t (*WS2812FX_mode_ptr)(void);
	typedef struct Segment   // 20 bytes
	{
		uint16_t start;
		uint16_t stop;
		uint16_t speed;
		uint8_t  mode;
		uint8_t  options;
		uint32_t colors[MAX_NUM_COLORS];
	} segment;
	typedef struct Segment_runtime   // 16 bytes
	{
		unsigned long next_time;
		uint32_t counter_mode_step;
		uint32_t counter_mode_call;
		uint8_t aux_param;   // auxilary param (usually stores a color_wheel index)
		uint8_t aux_param2;  // auxilary param (usually stores bitwise options)
		uint16_t aux_param3; // auxilary param (usually stores a segment index)
	} segment_runtime;
	void WS2812FX_Init(void);
	void
		WS2812FX_service(void),
		WS2812FX_init(void),
		WS2812FX_start(void),
		WS2812FX_stop(void),
		WS2812FX_pause(void),
		WS2812FX_resume(void),
		WS2812FX_strip_off(void),
		WS2812FX_fade_out_void(void),
		WS2812FX_fade_out_u32(uint32_t),
		WS2812FX_setMode_param1(uint8_t m),
		WS2812FX_setMode_param2(uint8_t seg, uint8_t m),
		WS2812FX_setOptions(uint8_t seg, uint8_t o),
		WS2812FX_setCustomMode(uint16_t (*p)()),
		WS2812FX_setCustomShow(void (*p)()),
		WS2812FX_setSpeed_param1(uint16_t s),
		WS2812FX_setSpeed_param2(uint8_t seg, uint16_t s),
		WS2812FX_increaseSpeed(uint8_t s),
		WS2812FX_decreaseSpeed(uint8_t s),
		WS2812FX_setColor_rgb(uint8_t r, uint8_t g, uint8_t b),
		WS2812FX_setColor_rgbw(uint8_t r, uint8_t g, uint8_t b, uint8_t w),
		WS2812FX_setColor_u32(uint32_t c),
		WS2812FX_setColor_seg(uint8_t seg, uint32_t c),
		WS2812FX_setColors(uint8_t seg, uint32_t* c),
		WS2812FX_setBrightness(uint8_t b),
		WS2812FX_increaseBrightness(uint8_t s),
		WS2812FX_decreaseBrightness(uint8_t s),
		WS2812FX_trigger(void),
		WS2812FX_setCycle(void),
		WS2812FX_setNumSegments(uint8_t n),
		WS2812FX_setSegment_color_reverse(uint8_t n, uint16_t start, uint16_t stop, uint8_t mode, uint32_t color,          uint16_t speed, bool reverse),
		WS2812FX_setSegment_color_opt(uint8_t n, uint16_t start, uint16_t stop, uint8_t mode, uint32_t color,          uint16_t speed, uint8_t options),
		WS2812FX_setSegment_colors_reverse(uint8_t n, uint16_t start, uint16_t stop, uint8_t mode, const uint32_t colors[], uint16_t speed, bool reverse),
		WS2812FX_setSegment_colors_opt(uint8_t n, uint16_t start, uint16_t stop, uint8_t mode, const uint32_t colors[], uint16_t speed, uint8_t options),
		WS2812FX_setIdleSegment_color_opt(uint8_t n, uint16_t start, uint16_t stop, uint8_t mode, uint32_t color,          uint16_t speed, uint8_t options),
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

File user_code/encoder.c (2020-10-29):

#include <stdio.h>
#include "stm32g0xx_ll_gpio.h"

#include "encoder.h"

//如果计数方向相反，用这个换一下
#define CHANGE_DIRECTION

// 编码器速率
// #define ENCODER_RATE_1_LOW  // 适用于静止时A、B相都为低电平
#define ENCODER_RATE_1_HIGH // 适用于静止时A、B相都为高电平
// #define ENCODER_RATE_2
// #define ENCODER_RATE_4

// 函数内部用于记录编码器按键的状态
#define ENCODER_KEY_STA_RELEASE 0x00
#define ENCODER_KEY_STA_IF_PUSH 0x01
#define ENCODER_KEY_STA_PUSH 0x02
#define ENCODER_KEY_STA_IF_RELEASE 0x03


static unsigned char EncoderKeyRet = ENCODER_KEY_NULL;
static unsigned char EncoderKeyState = ENCODER_KEY_STA_RELEASE; // 见宏定义

static char EncoderCount = 0;
static unsigned char EncoderState = 0;

#define ENCODER_IO_KEY LL_GPIO_IsInputPinSet(GPIOB, LL_GPIO_PIN_1)
#define ENCODER_IO_A LL_GPIO_IsInputPinSet(GPIOB, LL_GPIO_PIN_2)
#define ENCODER_IO_B LL_GPIO_IsInputPinSet(GPIOB, LL_GPIO_PIN_3)


void EncoderInit()
{
	//IO初始化
	// ENCODER_IO_A = 1;
	// ENCODER_IO_B = 1;
	// ENCODER_IO_KEY = 1;
}

// 编码器扫描函数，放到定时器中断服务函数里
void EncoderScan(void)
{
	// EncoderPA = ENCODER_IO_A;
	// EncoderPB = ENCODER_IO_B;
	
	//按键扫描
	if((EncoderKeyState == ENCODER_KEY_STA_RELEASE) && ENCODER_IO_KEY == 0)
	{
		EncoderKeyState = ENCODER_KEY_STA_IF_PUSH;
	}
	else if((EncoderKeyState == ENCODER_KEY_STA_IF_PUSH) && ENCODER_IO_KEY == 0)
	{
		EncoderKeyState = ENCODER_KEY_STA_PUSH;
		// 按键第一次按下
		EncoderKeyRet = ENCODER_KEY_PRESS;
	}
	else if((EncoderKeyState == ENCODER_KEY_STA_PUSH) && ENCODER_IO_KEY == 0)
	{
		// 按键持续按下
		EncoderKeyRet = ENCODER_KEY_PRESS;
	}
	else if((EncoderKeyState == ENCODER_KEY_STA_PUSH) && ENCODER_IO_KEY == 1)
	{
		EncoderKeyState = ENCODER_KEY_STA_IF_RELEASE;
	}
	else if((EncoderKeyState == ENCODER_KEY_STA_IF_RELEASE) && ENCODER_IO_KEY == 1)
	{
		EncoderKeyState = ENCODER_KEY_STA_RELEASE;
		// 按键释放
		EncoderKeyRet = ENCODER_KEY_RELEASE;
	}
	
	//	Read new state bits
	if (ENCODER_IO_A)
	{
		EncoderState |= 0x02;
	}
	if (ENCODER_IO_B)
	{
		EncoderState |= 0x01;
	}

#ifdef ENCODER_RATE_1_LOW
	switch (EncoderState)
	{
		case 0x01:
			EncoderCount -= 1;
			break;
		case 0x02:
			EncoderCount += 1;
			break;
		default:
			break;
	}
#endif

#ifdef ENCODER_RATE_1_HIGH
	switch (EncoderState)
	{
		case 0x0E:
			EncoderCount -= 1;
			break;
		case 0x0D:
			EncoderCount += 1;
			break;
		default:
			break;
	}
#endif

#ifdef ENCODER_RATE_2
	switch (EncoderState)
	{
		case 0x01:
		case 0x0E:
			EncoderCount -= 1;
			break;
		case 0x02:
		case 0x0D:
			EncoderCount += 1;
			break;
		default:
			break;
	}
#endif

#ifdef ENCODER_RATE_4
	switch (EncoderState)
	{
		case 0x01:
		case 0x07:
		case 0x08:
		case 0x0E:
			EncoderCount -= 1;
			break;
		case 0x02:
		case 0x04:
		case 0x0B:
		case 0x0D:
			EncoderCount += 1;
			break;
		case 0x03:
		case 0x0C:
			EncoderCount -= 2;
			break;
		case 0x06:
		case 0x09:
			EncoderCount += 2;
			break;
		default:
		//case 0x00:
		//case 0x05:
		//case 0x0A:
		//case 0x0F:
			//EncoderCount += 0;
			break;
	}
#endif
	
	// 更新状态
	EncoderState <<= 2;
	// 清除其他状态位
	EncoderState &= 0x0C;

	return;
}

char ReadEncoder()
{
	char c = 0;
	
	if(EncoderCount == 0)
	{
		return 0;
	}
	else 
	{
		#ifdef CHANGE_DIRECTION
		c = -EncoderCount;
		#else
		c = EncoderCount;
		#endif
		EncoderCount = 0;//读取按键后将编码器计数清零
		return c;
	}
}

unsigned char ReadEncoderKey()
{
	char c = 0;
	
	if(EncoderKeyRet == ENCODER_KEY_NULL)
	{
		return 0;
	}
	else 
	{
		c = EncoderKeyRet;
		EncoderKeyRet = ENCODER_KEY_NULL; // 读取按键后将按键清零
		return c;
	}
}

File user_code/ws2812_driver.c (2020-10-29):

/*
适配 Adafruit_NeoPixel
实现了部分接口，能满足基本使用
*/

#include "ws2812_driver.h"

#include <string.h>


#include "stm32g0xx_ll_gpio.h"
#include "user_hw_init.h"


// O0优化
// #define WS2812_DELAY1() \
// __NOP();__NOP();__NOP();__NOP();

// #define WS2812_DELAY2() \
// __NOP();__NOP();__NOP();__NOP(); \
// __NOP();__NOP();__NOP();__NOP(); \
// __NOP();__NOP();__NOP();__NOP(); \
// __NOP();__NOP();__NOP();__NOP(); \
// __NOP();__NOP();__NOP();__NOP();

// #define WS2812_DELAY3() \
// __NOP();__NOP();__NOP();__NOP(); \
// __NOP();__NOP();


// O3优化
#define WS2812_DELAY1() \
__NOP();__NOP();__NOP();__NOP(); \
__NOP();__NOP();__NOP();__NOP(); \
__NOP();__NOP();__NOP();__NOP(); \
__NOP();__NOP();

#define WS2812_DELAY2() \
__NOP();__NOP();__NOP();__NOP(); \
__NOP();__NOP();__NOP();__NOP(); \
__NOP();__NOP();__NOP();__NOP(); \
__NOP();__NOP();__NOP();__NOP(); \
__NOP();__NOP();__NOP();__NOP(); \
__NOP();__NOP();__NOP();__NOP(); \
__NOP();__NOP();

#define WS2812_DELAY3() \
__NOP();__NOP();__NOP();__NOP(); \
__NOP();__NOP();__NOP();__NOP(); \
__NOP();__NOP();

uint32_t ws2812_buf[WS2812_LED_NUMS] = {0};
uint8_t ws2812_brightness;
// uint16_t ws2812_numBytes = WS2812_LED_NUMS;
uint16_t ws2812_numBytes = sizeof(ws2812_buf);

void ws2812_init(void)
{
	// GPIO init
}

void ws2812_reset(void)
{
	LL_GPIO_SetOutputPin(GPIOA, LL_GPIO_PIN_1);
	delay_us(10);
	LL_GPIO_ResetOutputPin(GPIOA, LL_GPIO_PIN_1);
	delay_us(60);
}

void ws2812_write_byte(uint8_t dat)
{
	uint8_t i = 8;

	while (i)
	{
		LL_GPIO_SetOutputPin(GPIOA, LL_GPIO_PIN_1);
		WS2812_DELAY1();
		if(!(dat & 0x80))
		{
			LL_GPIO_ResetOutputPin(GPIOA, LL_GPIO_PIN_1);
		}
		WS2812_DELAY2();
		LL_GPIO_ResetOutputPin(GPIOA, LL_GPIO_PIN_1);
		WS2812_DELAY3();

		dat <<= 1;
		i--;
	}
}

//数组按RGB顺序存储，输出GRB
void ws2812_write_color_rgb(uint8_t *color)
{
	__disable_irq();
	ws2812_write_byte(color[1]);
	ws2812_write_byte(color[0]);
	ws2812_write_byte(color[2]);
	__enable_irq();
}

//高字节忽略，剩下三字节按RGB顺序存储，输出GRB
void ws2812_write_color_u32(uint32_t color)
{
	__disable_irq();
	// 存储格式wrgb
	ws2812_write_byte((color >> 8) & 0xFF);
	ws2812_write_byte((color >> 16) & 0xFF);
	ws2812_write_byte(color & 0xFF);
	__enable_irq();

}

// 将缓存的颜色全部写入灯带
void ws2812_write_all(void)
{
	int i = 0;
	for (i = 0; i < WS2812_LED_NUMS; i++)
	{
		ws2812_write_color_u32(ws2812_buf[i]);
	}
}

void ws2812_clear(void)
{
	memset(ws2812_buf, 0, sizeof(uint32_t) * WS2812_LED_NUMS);
}

void ws2812_fill(uint32_t c, uint16_t first, uint16_t count)
{
	uint16_t i, end;

	if(first >= WS2812_LED_NUMS)
	{
		return; // If first LED is past end of strip, nothing to do
	}

	// Calculate the index ONE AFTER the last pixel to fill
	if(count == 0)
	{
		// Fill to end of strip
		end = WS2812_LED_NUMS;
	}
	else
	{
		// Ensure that the loop won't go past the last pixel
		end = first + count;
		if(end > WS2812_LED_NUMS) end = WS2812_LED_NUMS;
	}

	for(i = first; i < end; i++)
	{
		ws2812_set_color_u32(i, c);
	}
}

/*
//按wbgr顺序存储
//有白色的话高8位作为白色
//否则高8位忽略，剩下24位按RGB顺序存储，输出GRB
void ws2812_set_color_rgbw(uint32_t n, uint8_t r, uint8_t g, uint8_t b, uint8_t w)
{
	// ws2812_buf[n] = (w << 24) + (b << 16) + (g << 8) + r;
	ws2812_buf[n] = (b << 16) + (g << 8) + r;
}

void ws2812_set_color_uint32(uint32_t n, uint32_t color)
{
	ws2812_buf[n] = color;
}
*/


//按wrgb顺序存储
//有白色的话高8位作为白色
//否则高8位忽略，剩下24位按RGB顺序存储，输出GRB
void ws2812_set_color_rgbw(uint32_t n, uint8_t r, uint8_t g, uint8_t b, uint8_t w)
{
	// ws2812_buf[n] = (w << 24) + (r << 16) + (g << 8) + b;
	ws2812_buf[n] = (r << 16) + (g << 8) + b;
}

void ws2812_set_color_u32(uint32_t n, uint32_t color)
{
	ws2812_buf[n] = color;
}




















/* A PROGMEM (flash mem) table containing 8-bit unsigned sine wave (0-255).
   Copy & paste this snippet into a Python REPL to regenerate:
import math
for x in range(256):
    print("{:3},".format(int((math.sin(x/128.0*math.pi)+1.0)*127.5+0.5))),
    if x&15 == 15: print
*/
static const uint8_t _NeoPixelSineTable[256] =
{
	128, 131, 134, 137, 140, 143, 146, 149, 152, 155, 158, 162, 165, 167, 170, 173,
	176, 179, 182, 185, 188, 190, 193, 196, 198, 201, 203, 206, 208, 211, 213, 215,
	218, 220, 222, 224, 226, 228, 230, 232, 234, 235, 237, 238, 240, 241, 243, 244,
	245, 246, 248, 249, 250, 250, 251, 252, 253, 253, 254, 254, 254, 255, 255, 255,
	255, 255, 255, 255, 254, 254, 254, 253, 253, 252, 251, 250, 250, 249, 248, 246,
	245, 244, 243, 241, 240, 238, 237, 235, 234, 232, 230, 228, 226, 224, 222, 220,
	218, 215, 213, 211, 208, 206, 203, 201, 198, 196, 193, 190, 188, 185, 182, 179,
	176, 173, 170, 167, 165, 162, 158, 155, 152, 149, 146, 143, 140, 137, 134, 131,
	128, 124, 121, 118, 115, 112, 109, 106, 103, 100, 97, 93, 90, 88, 85, 82,
	79, 76, 73, 70, 67, 65, 62, 59, 57, 54, 52, 49, 47, 44, 42, 40,
	37, 35, 33, 31, 29, 27, 25, 23, 21, 20, 18, 17, 15, 14, 12, 11,
	10,  9,  7,  6,  5,  5,  4,  3,  2,  2,  1,  1,  1,  0,  0,  0,
	0,  0,  0,  0,  1,  1,  1,  2,  2,  3,  4,  5,  5,  6,  7,  9,
	10, 11, 12, 14, 15, 17, 18, 20, 21, 23, 25, 27, 29, 31, 33, 35,
	37, 40, 42, 44, 47, 49, 52, 54, 57, 59, 62, 65, 67, 70, 73, 76,
	79, 82, 85, 88, 90, 93, 97, 100, 103, 106, 109, 112, 115, 118, 121, 124
};

/* Similar to above, but for an 8-bit gamma-correction table.
   Copy & paste this snippet into a Python REPL to regenerate:
import math
gamma=2.6
for x in range(256):
    print("{:3},".format(int(math.pow((x)/255.0,gamma)*255.0+0.5))),
    if x&15 == 15: print
*/
static const uint8_t _NeoPixelGammaTable[256] =
{
	0,  0,  0,  0,  0,  0,  0,  0,  0,  0,  0,  0,  0,  0,  0,  0,
	0,  0,  0,  0,  0,  0,  0,  0,  1,  1,  1,  1,  1,  1,  1,  1,
	1,  1,  1,  1,  2,  2,  2,  2,  2,  2,  2,  2,  3,  3,  3,  3,
	3,  3,  4,  4,  4,  4,  5,  5,  5,  5,  5,  6,  6,  6,  6,  7,
	7,  7,  8,  8,  8,  9,  9,  9, 10, 10, 10, 11, 11, 11, 12, 12,
	13, 13, 13, 14, 14, 15, 15, 16, 16, 17, 17, 18, 18, 19, 19, 20,
	20, 21, 21, 22, 22, 23, 24, 24, 25, 25, 26, 27, 27, 28, 29, 29,
	30, 31, 31, 32, 33, 34, 34, 35, 36, 37, 38, 38, 39, 40, 41, 42,
	42, 43, 44, 45, 46, 47, 48, 49, 50, 51, 52, 53, 54, 55, 56, 57,
	58, 59, 60, 61, 62, 63, 64, 65, 66, 68, 69, 70, 71, 72, 73, 75,
	76, 77, 78, 80, 81, 82, 84, 85, 86, 88, 89, 90, 92, 93, 94, 96,
	97, 99, 100, 102, 103, 105, 106, 108, 109, 111, 112, 114, 115, 117, 119, 120,
	122, 124, 125, 127, 129, 130, 132, 134, 136, 137, 139, 141, 143, 145, 146, 148,
	150, 152, 154, 156, 158, 160, 162, 164, 166, 168, 170, 172, 174, 176, 178, 180,
	182, 184, 186, 188, 191, 193, 195, 197, 199, 202, 204, 206, 209, 211, 213, 215,
	218, 220, 223, 225, 227, 230, 232, 235, 237, 240, 242, 245, 247, 250, 252, 255
};
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

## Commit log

2020-10-28 新建工程
2020-10-28 新增腾讯at sdk
2020-10-29 新增应用程序代码
2020-10-29 新增用户配置文件
2020-10-29 修改色温步长
2020-10-30 优化灯光控制逻辑
2020-11-01 添加原理图及PCB
    [BOM_E53接口LED驱动模块.csv]
2020-11-01 添加灯管外壳设计图
    [灯管外壳.dwg]
2020-11-01 添加datasheet
2020-11-01 添加图片
2020-11-01 更新文档
2020-11-04 添加STM32G070开发板原理图
2020-11-08 更新图片
2020-11-18 重命名 doc/pic/200.PNG 为 doc/pic/200.PNGpng
2020-11-18 重命名 doc/pic/200.PNGpng 为 doc/pic/200.png
2020-11-18 重命名 doc/pic/201.PNG 为 doc/pic/201.PNGpng
2020-11-18 重命名 doc/pic/201.PNGpng 为 doc/pic/201.png
2020-11-18 重命名 doc/pic/202.PNG 为 doc/pic/202.PNGpng
2020-11-18 重命名 doc/pic/202.PNGpng 为 doc/pic/202.png
2020-11-18 重命名 doc/pic/203.PNG 为 doc/pic/203.PNGpng
2020-11-18 重命名 doc/pic/203.PNGpng 为 doc/pic/203.png
2020-11-18 重命名 doc/pic/204.PNG 为 doc/pic/204.PNGpng
2020-11-18 重命名 doc/pic/204.PNGpng 为 doc/pic/204.png
2020-12-07 无操作一段时间后关闭OLED屏，尽可能降低烧屏痕迹，延长屏幕寿命

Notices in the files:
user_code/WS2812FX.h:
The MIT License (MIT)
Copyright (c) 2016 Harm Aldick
